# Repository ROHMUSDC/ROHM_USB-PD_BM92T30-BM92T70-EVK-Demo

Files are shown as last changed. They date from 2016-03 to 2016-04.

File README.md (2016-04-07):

# ROHM USB-PD DP Alt Mode EVK - DP/USB3.0 Source and Sink Demonstrations
* PN: BM92T30-HOST-EVK-101 (occasionally referred to as "EVK1")
* PN: BM92T70-DEVICE-EVK-101 (occasionally referred to as "EVK2")
* Description:  This Evaluation Kit will demonstrate ROHM's USB-PD Solution in conjunction with Pericom's SS MUX to provide a USB-PD Solution for USB Type C Applications
* Developer: USDC Applications Engineering Team, ROHM Semiconductor
* Repository Generated: April 2016

----
### General Information
* If you have any questions about any of this technical information, please feel free to reach out to us as engineering@rohmsemiconductor.com
* Please note that detailed technical notes explaining the USB-PD IC register mapping is not available for this IC in this repository and requires an NDA with ROHM for this information.
	* Please reach out to your ROHM sales manager, visit https://www.rohm.com/web/global/contactus or send a message to engineering@rohmsemiconductor.com to establish this NDA for additional information.

----
### Repository Contents
* Documentation Folder: Contains the latest HW PDF files, USB-PD General Datasheets, and Board Manual
* Hardware Design Files: Contains the Schematic/BOM/Gerber Source files for these EVK development boards

-----
### Video Demonstrations

* ROHM Evaluation Board Video Demo, BM92T30-HOST-EVK-101 (April 2016):
	* https://youtu.be/YEIDfTC97i4

* ROHM Evaluation Board Video Demo, BM92T70-DEVICE-EVK-101 (April 2016):
	* https://youtu.be/2LjfqHi3JEg 

* ROHM USBPD Type-C Alt Mode Demo PART1: DisplayPort Monitor Connection Demo (OLD-Live Demo, From 2015)
	* https://www.youtube.com/watch?v=6yjsj-j72X8

* ROHM USBPD Type-C Alt Mode Demo PART2: USB3.0 Super Speed Demo (OLD-Live Demo, From 2015)
	* https://www.youtube.com/watch?v=sI1nSPhlAow

-----
### Frequently Asked Questions (FAQ)
* Q: For EVK2, the documentation refers to REV04 but the design files listed here are REV05.  What is the difference.
* A: REV05 and REV04 are functionally identical.  Only change between EVK2 REV04 and REV05 is a fix of a broken net that was missed during the development of these boards.

----
### DISCLAIMER
This Technical Data is protected under copyright laws.

ROHM hereby grants you a nonexclusive, nontransferable license to use this Technical Data 
as long as you abide by the terms and conditions of this DISCLAIMER. 

However, you are not authorized to sell, loan, rent, lease, redistribute or license this Technical Data, 
in whole or in part, or in modified form, to anyone.

You may modify this Technical Data to suit your specific applications, 
but the rights to derivative works and said modifications shall belong to ROHM. 

You may make copies of this Technical Data as necessary for internal use only within your company.

ROHM shall not be responsible for ensuring proper application on all computer systems.
This Technical Data is provided AS IS. ROHM makes no guarantees, either implicitly or explicitly, 
regarding its usability, functionality, accuracy, merchantability, or fitness for a specific purpose.

In addition, you shall take full responsibility for the use of any information acquired from this Technical Data. 

ROHM does not assume warranty of any kind arising from the use of this Technical Data. ACCORDINGLY, 
IN NO EVENT SHALL ROHM BE RESPONSIBLE, WHETHER THROUGH CONTRACT OR TORT LIABILITY, 
FOR ANY DAMAGES (INCLUDING BUT NOT LIMITED TO LOST PROFITS OR OTHER INCIDENTAL, CONSEQUENTAL, 
OR PUNITIVE DAMAGES) ARISING OUT OF OR IN CONNECTION WITH THE USE OR APPLICATION OF THIS Technical Data.

Furthermore, this Technical Data is subject to change without notice.

Unless otherwise expressly provided herein, ROHM does not convey any license under patent rights 
or any other intellectual property rights (including those of third parties).

ROHM is not obligated to provide maintenance or support for the Technical Data.

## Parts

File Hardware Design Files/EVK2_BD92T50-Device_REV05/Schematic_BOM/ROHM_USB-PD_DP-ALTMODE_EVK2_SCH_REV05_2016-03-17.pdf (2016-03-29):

# ROHM USB-PD Type-C DP Alt Mode EVK2 - Device/UFP

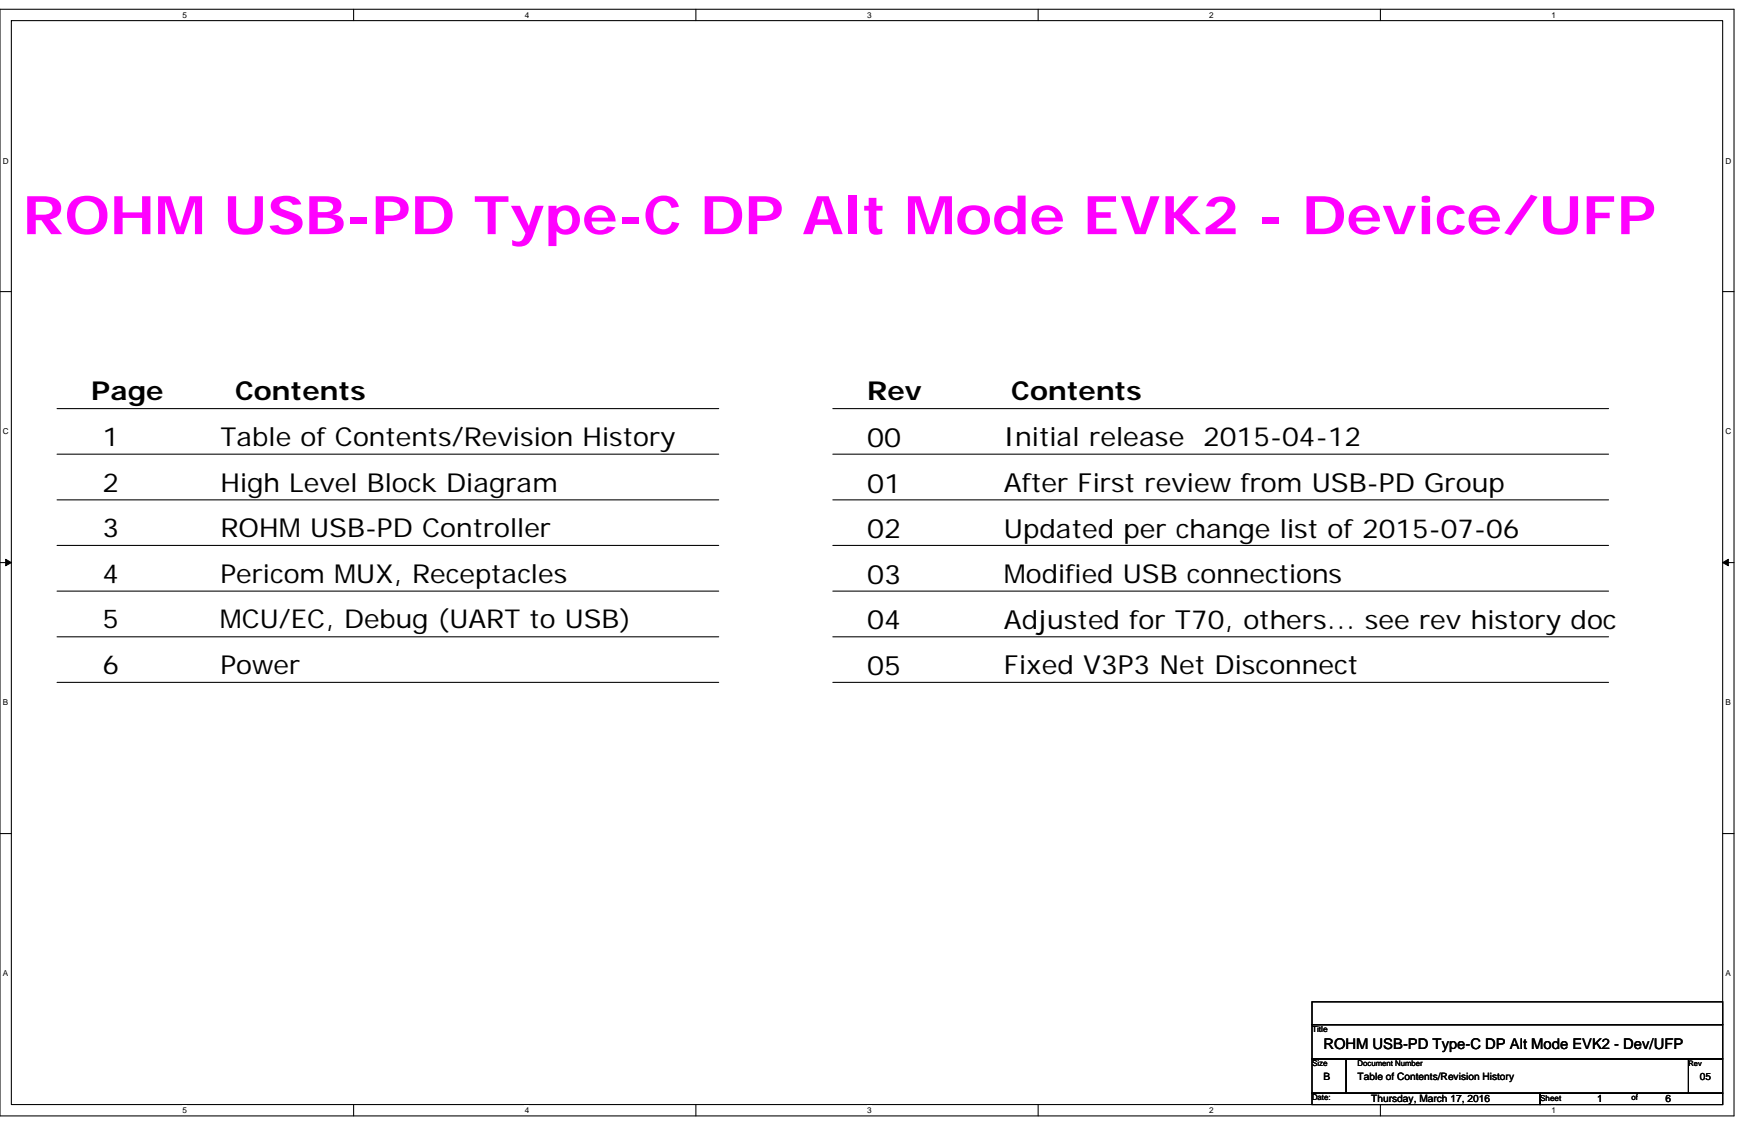
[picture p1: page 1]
Page; Contents; Table of Contents/Revision History; ROHM USB-PD Controller; Pericom MUX, Receptacles; Rev; Initial release 2015-04-12; MCU/EC, Debug (UART to USB); After First review from USB-PD Group; Updated per change list of 2015-07-06; Modified USB connections; Adjusted for T70, others... see rev history doc; Power; High Level Block Diagram; Fixed V3P3 Net Disconnect

Title
ROHM USB-PD Type-C DP Alt Mode EVK2 - Dev/UFP

Size Size Size B B B | Document Number Document Number Document Number Table of Contents/Revision History Table of Contents/Revision History Table of Contents/Revision History | Rev Rev Rev 05 05 05

Date: Date: Date: Thursday, March 17, 2016 Thursday, March 17, 2016 Thursday, March 17, 2016 | Sheet Sheet Sheet 1 1 1 of of of 6 6 6

5

4

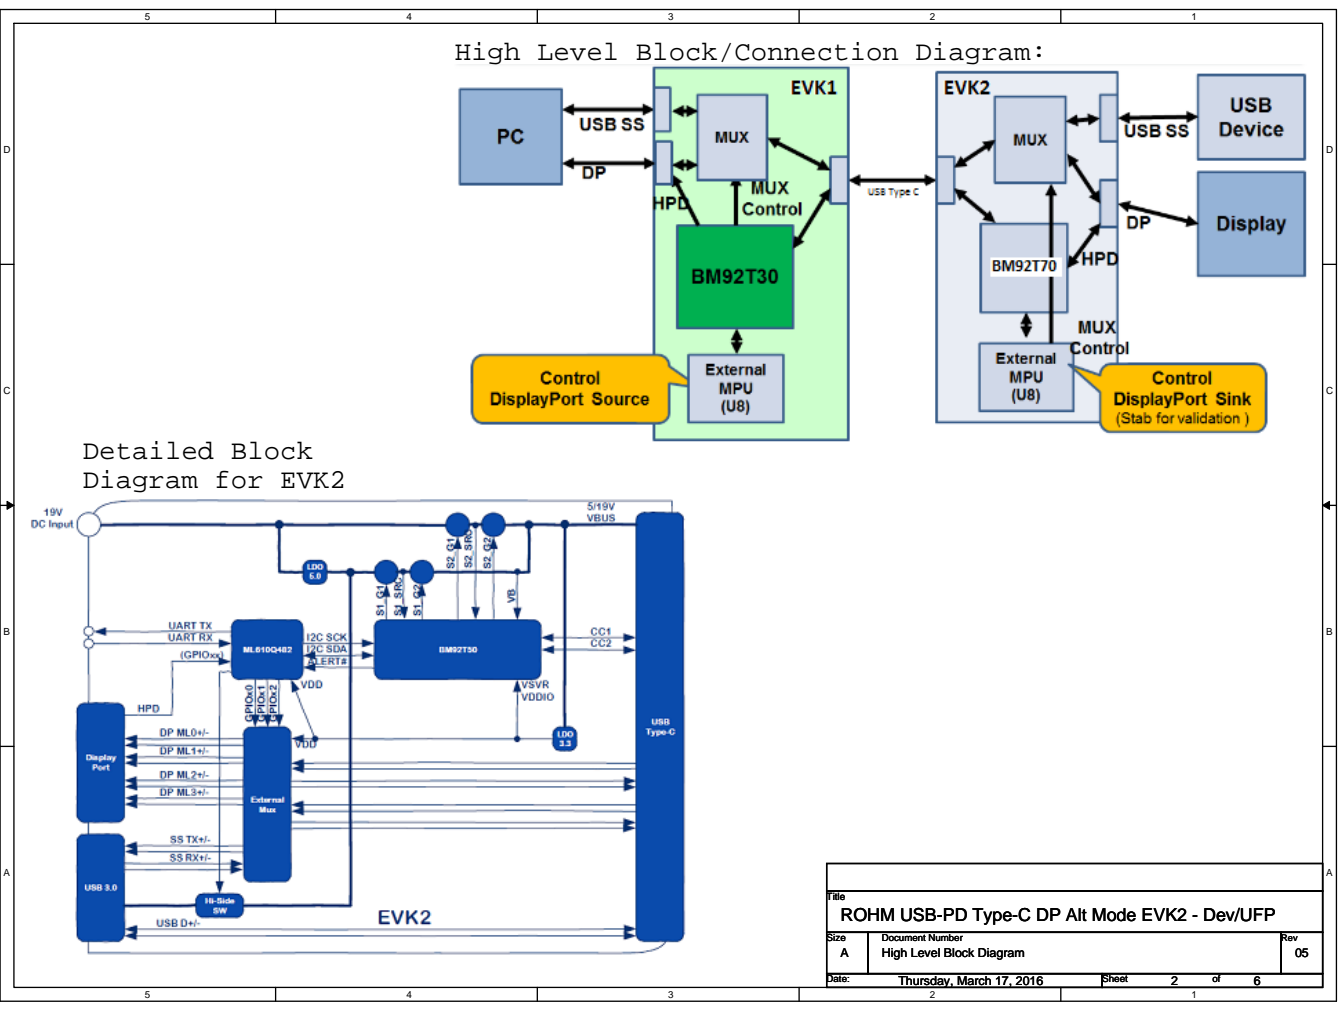
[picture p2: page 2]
Detailed Block Diagram for EVK2

High Level Block/Connection Diagram:

Title
ROHM USB-PD Type-C DP Alt Mode EVK2 - Dev/UFP

Size Size Size A A A | Document Number Document Number Document Number High Level Block Diagram High Level Block Diagram High Level Block Diagram | Rev Rev Rev 05 05 05

Date: Date: Date: Thursday, March 17, 2016 Thursday, March 17, 2016 Thursday, March 17, 2016 | Sheet Sheet Sheet 2 2 2 of of of 6 6 6

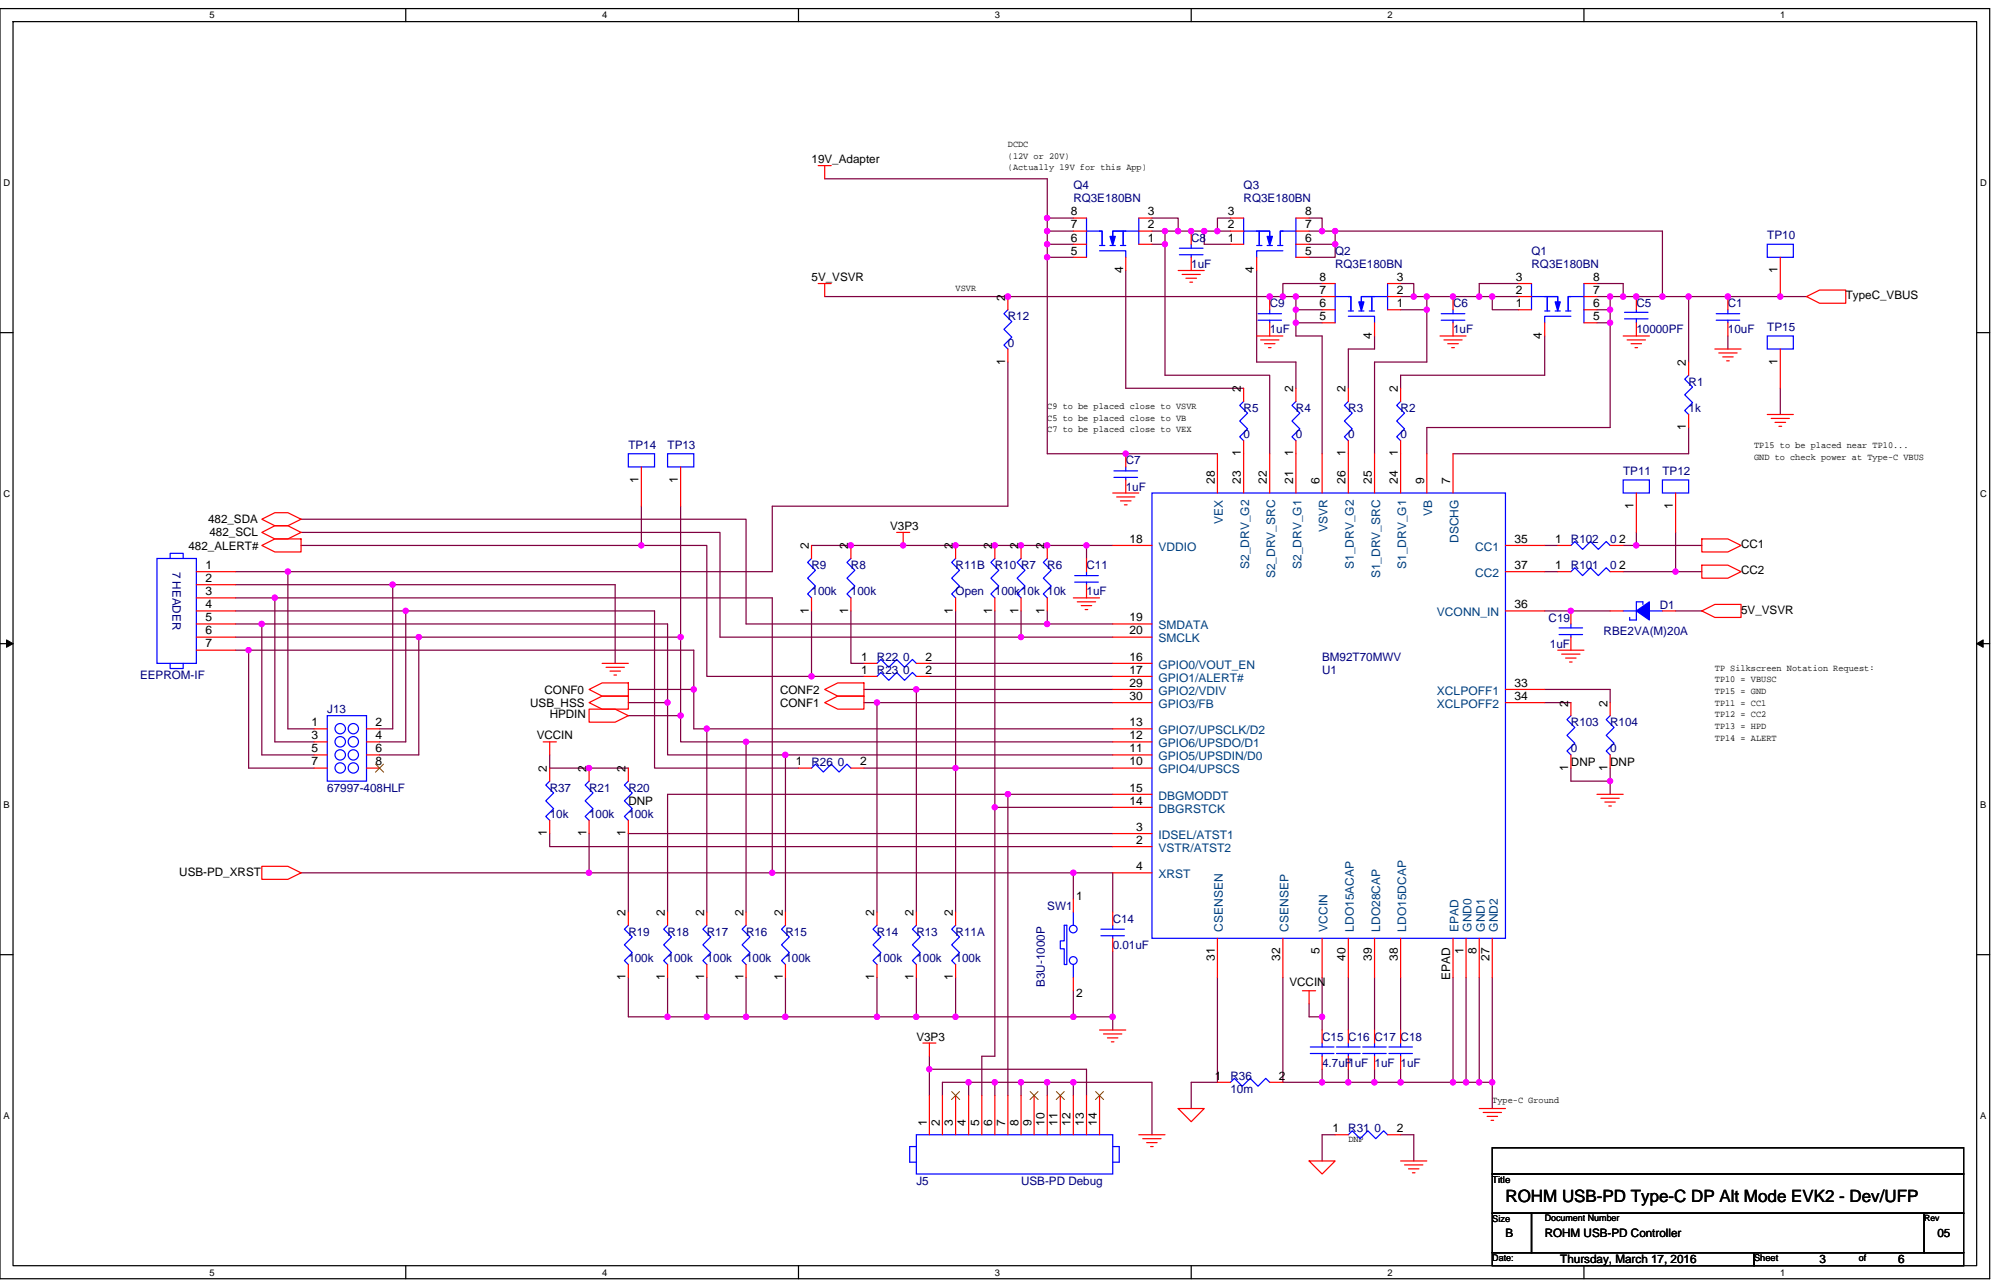
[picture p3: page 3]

DCDC
(Actually 19V for this App)

C9 to be placed close to VSVR
C5 to be placed close to VB
C7 to be placed close to VEX

TP15 to be placed near TP10...
GND to check power at Type-C VBUS

GPIO1/ALERT# 17
GPIO2/VDIV 29 GPIO3/FB 30

DBGRSTCK 14 DBGMODDT 15

VSTR/ATST2 2 IDSEL/ATST1 3

VCCIN | C15 | C16 | C17 | C18

Title
ROHM USB-PD Type-C DP Alt Mode EVK2 - Dev/UFP

Size Size Size B B B | Document Number Document Number Document Number ROHM USB-PD Controller ROHM USB-PD Controller ROHM USB-PD Controller | Rev Rev Rev 05 05 05

Date: Date: Date: Thursday, March 17, 2016 Thursday, March 17, 2016 Thursday, March 17, 2016 | Sheet Sheet Sheet 3 3 3 of of of 6 6 6

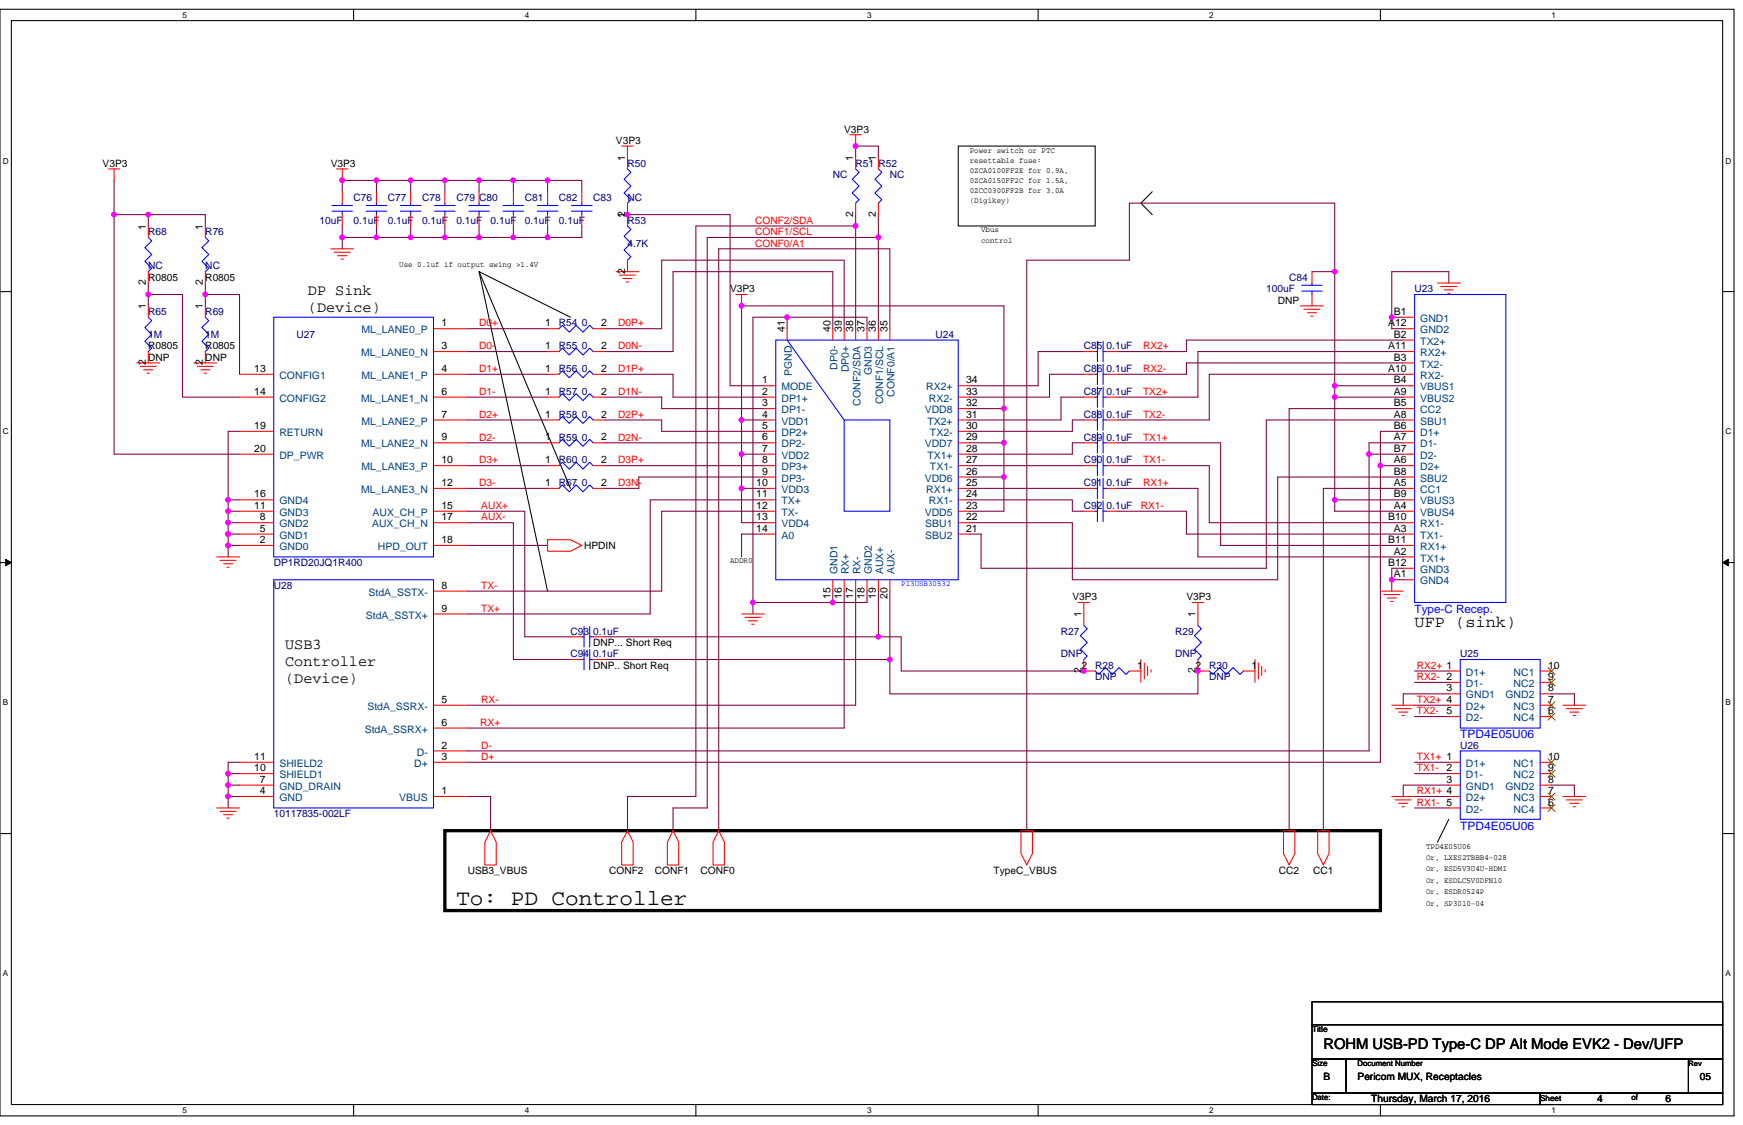
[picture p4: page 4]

Use 0.1uf if output swing >1.4V

Title
ROHM USB-PD Type-C DP Alt Mode EVK2 - Dev/UFP

Size Size Size B B B | Document Number Document Number Document Number Pericom MUX, Receptacles Pericom MUX, Receptacles Pericom MUX, Receptacles | Rev Rev Rev 05 05 05

Date: Date: Date: Thursday, March 17, 2016 Thursday, March 17, 2016 Thursday, March 17, 2016 | Sheet Sheet Sheet 4 4 4 of of of 6 6 6

# MCU - Acting EC for the USB-PD IC

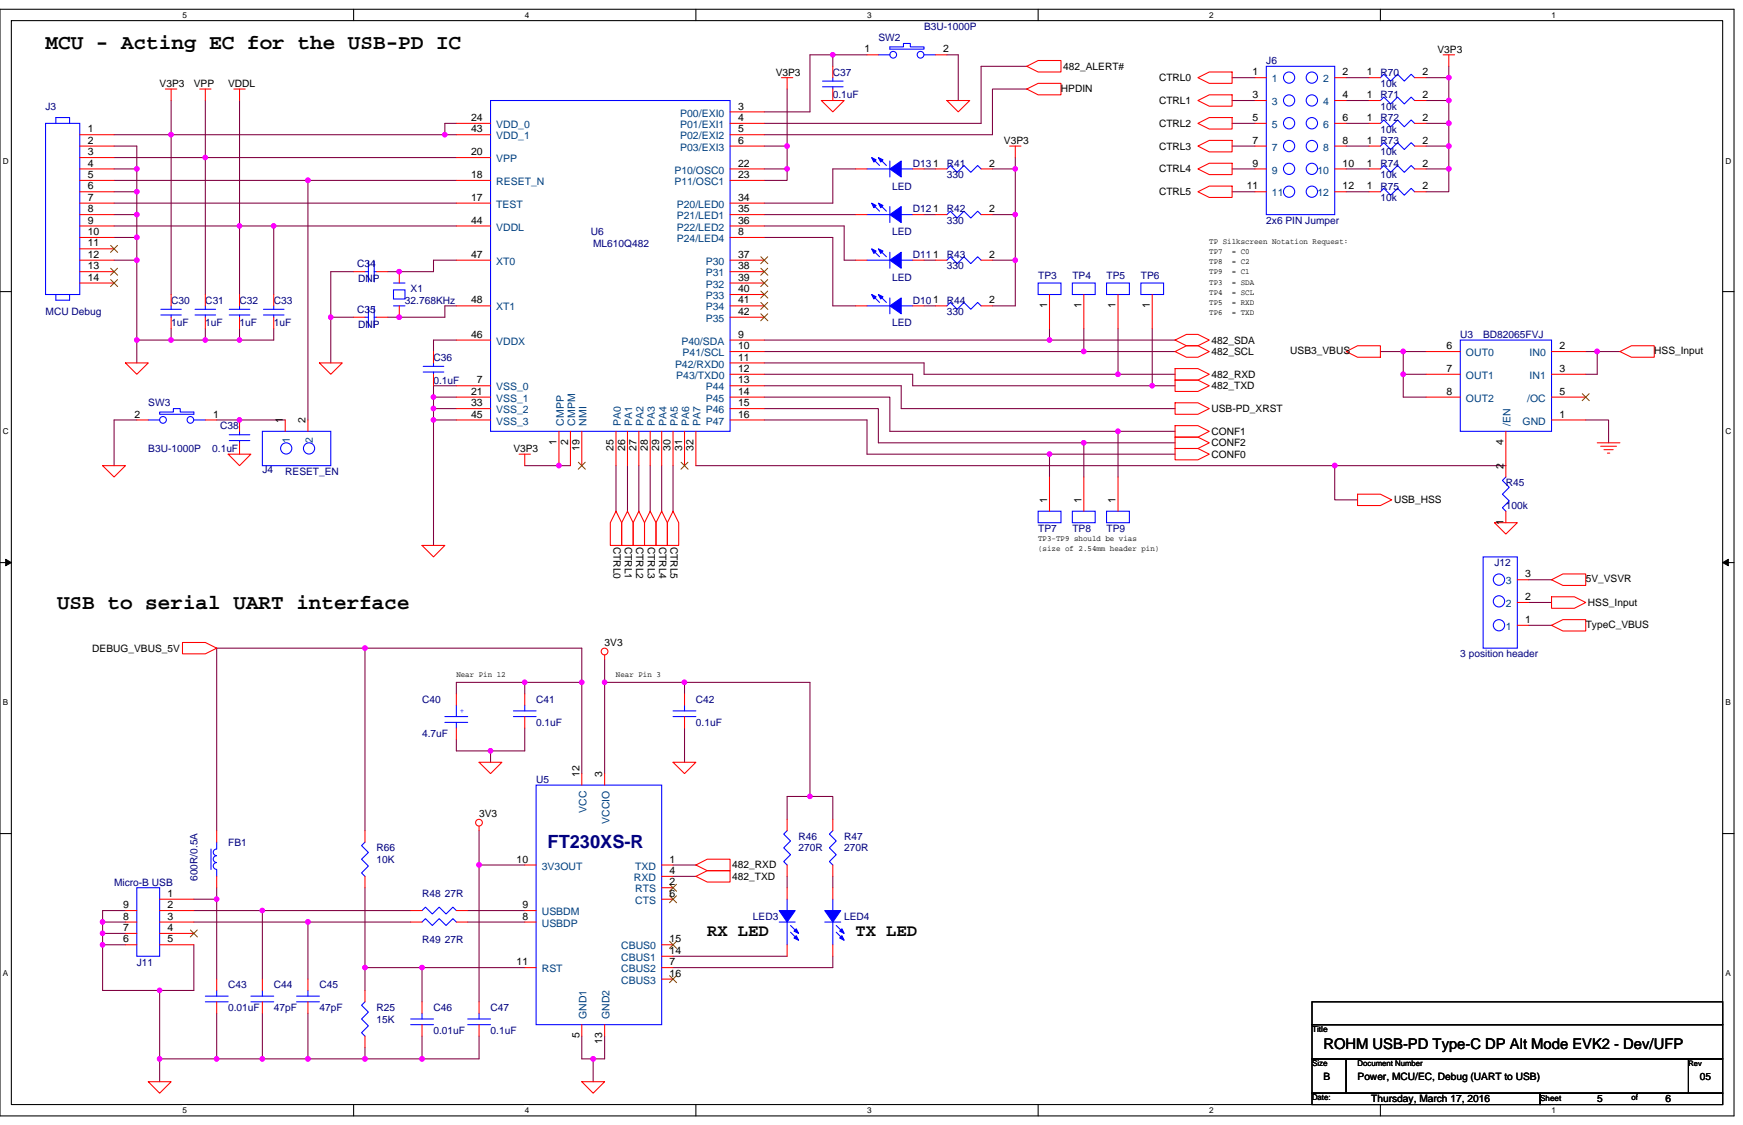
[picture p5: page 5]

TP3-TP9 should be vias
(size of 2.54mm header pin)

USB to serial UART interface

Title
ROHM USB-PD Type-C DP Alt Mode EVK2 - Dev/UFP

Size Size Size B B B | Document Number Document Number Document Number Power, MCU/EC, Debug (UART to USB) Power, MCU/EC, Debug (UART to USB) Power, MCU/EC, Debug (UART to USB) | Rev Rev Rev 05 05 05

Date: Date: Date: Thursday, March 17, 2016 Thursday, March 17, 2016 Thursday, March 17, 2016 | Sheet Sheet Sheet 5 5 5 of of of 6 6 6

5

4

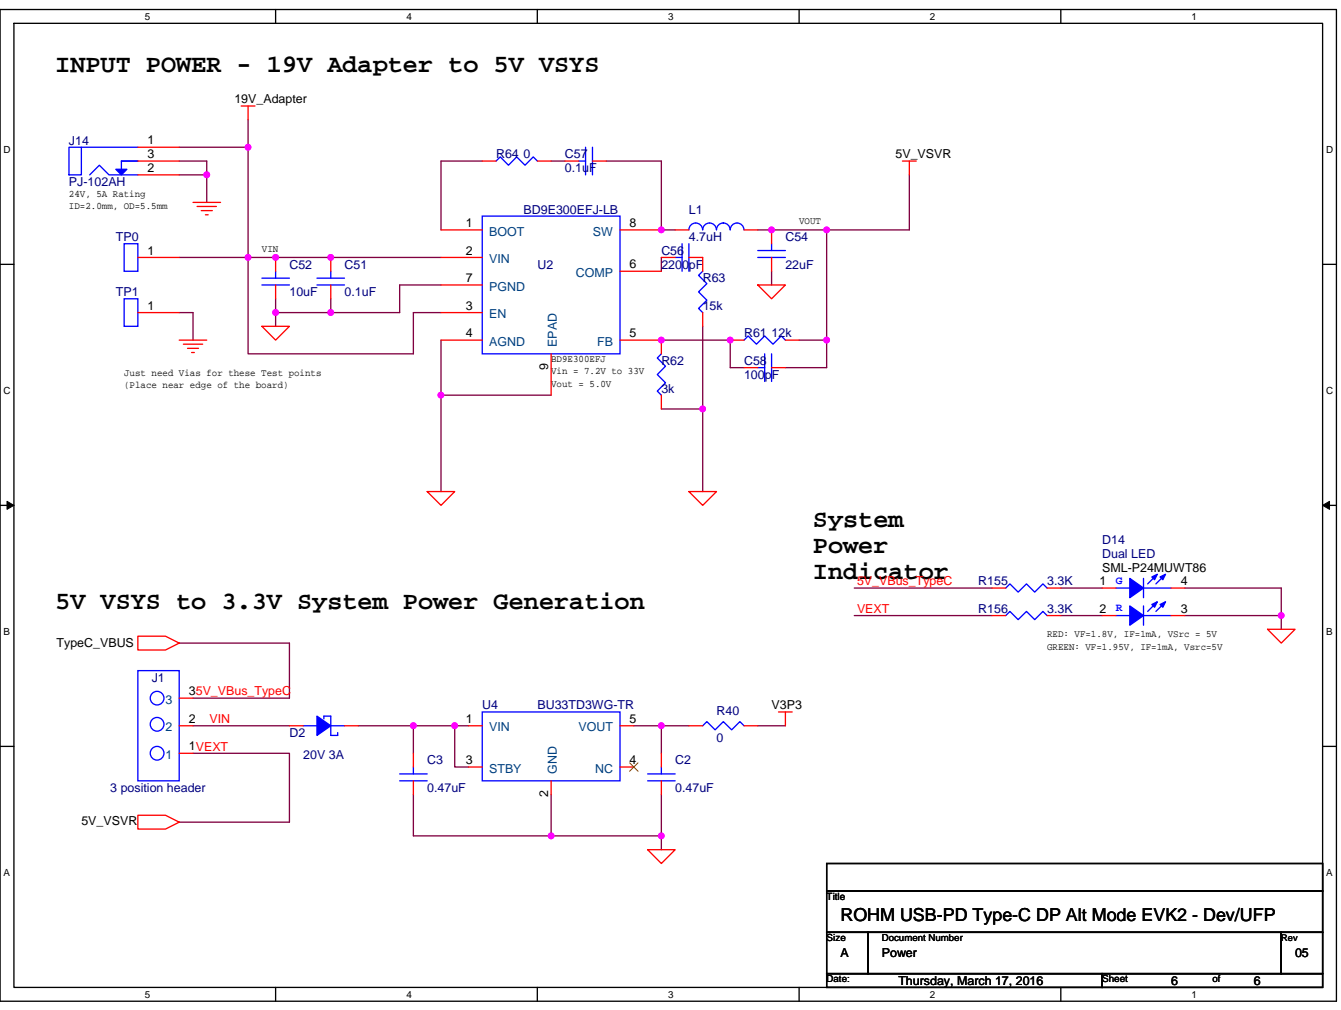
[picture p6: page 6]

INPUT POWER - 19V Adapter to 5V VSYS 19V_Adapter

PGND 7

Just need Vias for these Test points
(Place near edge of the board)

5V VSYS to 3.3V System Power Generation

RED: VF=1.8V, IF=1mA, VSrc = 5V
GREEN: VF=1.95V, IF=1mA, Vsrc=5V

Title
ROHM USB-PD Type-C DP Alt Mode EVK2 - Dev/UFP

Size Size Size A A A | Document Number Document Number Document Number Power Power Power | Rev Rev Rev 05 05 05

Date: Date: Date: Thursday, March 17, 2016 Thursday, March 17, 2016 Thursday, March 17, 2016 | Sheet Sheet Sheet 6 6 6 of of of 6 6 6

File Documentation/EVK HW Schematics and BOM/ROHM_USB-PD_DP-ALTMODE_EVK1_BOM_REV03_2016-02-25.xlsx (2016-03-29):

ROHM USB-PD Type-C DP Alt Mode EVK1 - Host/DFP Revised: Jan 21, 2016
Bill Of Materials
Item | Quantity | Reference | Part | PCB Footprint | DESCRIPTION | MANUFACTURER1 | MANUFACTURER1_PART# | Disty PN | Where to Source | QTY Required for 20 | QTY Required for 50 | DNP | Comments
1 | 1 | C1 | 10uF | C1206 | 10uF, 3216, X5R, 50V | Murata | GRM31CR61H106KA12L | 490-5961-1-ND | Digikey | 22 | 55
2 | 2 | C2,C3 | 0.47uF | C0402 | CAP CER 0.47UF 6.3V 10% X5R 0402 | Samsung | CL05A474KQ5NNNC | 1276-1479-1-ND | Digikey | 44 | 110
3 | 2 | C5,C14 | 0.01uF | C0402 | 0.01uF, 1005, X5R, 50V | TDK | CGA2B3X5R1H103K050BB | 445-12201-1-ND | Digikey | 44 | 110
4 | 7 | C6,C7,C12,C30,C31,C32,C33 | 1uF | C0603 | 1uF, 1608, X5R, 50V | TAIYO YUDEN | UMK107BJ105KA-T | 587-2400-1-ND | Digikey | 154 | 385
5 | 8 | C8,C9,C10,C11,C16,C17,C18,C19 | 1uF | C0402 | 1uF, 1005, X5R, 16V | Murata | GRM155R61C105ME01D | 490-10454-1-ND | Digikey | 176 | 440
6 | 1 | C15 | 4.7uF | C0402 | 4.7uF, 1005, X5R, 6.3V | TAIYO YUDEN | JMK105BBJ475MV-F | 587-2787-1-ND | Digikey | 22 | 55
7 | 18 | C36,C37,C38,C77,C78,C79,C80,C81,C82,C83,C85,C86,C87,C88,C89,C90,C91,C92 | 0.1uF | C0402 | CAP CER 0.1UF 10V 10% X5R 0402 | Murata | GRM155R61A104KA01D | 490-1318-1-ND | Digikey | 396 | 990
8 | 1 | C40 | 4.7uF | ECE-V1EA4R7SR | Cap, Polarized, 4.7uF | Panasonic | EEE-1EA4R7SR | PCE3910CT-ND | Digikey | 22 | 55
9 | 3 | C41,C42,C47 | 0.1uF | C0805 | Cap, Ceramic 0.1uF 0805 | TDK | C2012X7R2A104K | 445-1418-1-ND | Digikey | 66 | 165
10 | 2 | C43,C46 | 0.01uF | C0805 | Cap, Ceramic, 0.01uF 0805 | TDK | C2012X7R2E103K | 445-2280-1-ND | Digikey | 44 | 110
11 | 2 | C44,C45 | 47pF | C0805 | Cap, Ceramic, 47pF 0805 | Kemet | C0805C470J1GACTU | 399-8079-1-ND | Digikey | 44 | 110
12 | 1 | C76 | 10uF | C0603 | CAP CER 10UF 6.3V 20% X5R 0603 | Murata | GRM188R60J106ME47J | 490-6405-1-ND | Digikey | 22 | 55
13 | 1 | D1 | RBE2VA(M)20A | RBE2VAM20A | Schottky barrier diode,20V/2A Vf=0.46(2A)/0.39(1A) | ROHM | RBE2VA20ATR | N/A | Direct Sample from ROHM | 22 | 55
14 | 1 | D2 | 20V 3A | SOD-123F | DIODE SCHOTTKY 20V 3A PMDU | ROHM | RB051M-2YTR | N/A | Direct Sample from ROHM | 22 | 55
15 | 4 | D10,D11,D12,D13 | LED | LED0402 | LED 0402 RED 50MW 20MA SMD | ROHM | SML-P11VTT86 | N/A | Direct Sample from ROHM | 88 | 220
16 | 1 | D14 | Dual LED | LED0404-DUAL | LED PICOLED DUAL YWGN/RED 1010 | ROHM | SML-P24MUWT86 | N/A | Direct Sample from ROHM | 22 | 55
17 | 1 | EEPROM-IF | 7 HEADER | SM07B-SRSS-TB | 7pin connector | JST | SM07B-SRSS-TB(LF)(SN) | 455-1807-1-ND | Digikey | 22 | 55
18 | 1 | FB1 | 600R/0.5A | FB0805 | Ferrite Bead (600R/0.5A) | Laird | MI0805K601R-10 | 240-2390-1-ND | Digikey | 22 | 55
19 | 1 | J1 | 3 position header | HDR_THVT_1X3_100 | BERGSTIK II .100" SR STRAIGHT | FCI | 68000-103HLF | 609-3461-ND | Digikey | 22 | 55
20 | 2 | J2,J4 | 2 position header | HDR_THVT_1X2_100 | BERGSTIK II .100" SR STRAIGHT | FCI | 68000-102HLF | 609-3500-ND | Digikey | 44 | 110
21 | 1 | J3 | MCU Debug | HDR_THVT_2x7_100 | ThroughHole - 2x7 | FCI | 67996-114HLF | 609-3491-ND | Digikey | 22 | 55
22 | 1 | J5 | USB-PD Debug | HDR_THVT_2x7_100 | ThroughHole - 2x7 | FCI | 67996-114HLF | 609-3491-ND | Digikey | 22 | 55
23 | 1 | J11 | Micro-B USB | ZX62R-B-5P | micro USB receptacle | Hirose | ZX62R-B-5P | H11574CT-ND | Digikey | 22 | 55
24 | 1 | J12 | 67997-408HLF | HDR_2X4_100_VERT | CONN HEADER 8POS .100 STR TIN | FCI | 67997-408HLF | 609-3397-ND | Digikey | 22 | 55
25 | 1 | LED3 | Green | LED0805 | LED 570NM GREEN WTR CLR 0805 SMD | ROHM | SML-210MTT86 | N/A | Direct Sample from ROHM | 22 | 55
26 | 1 | LED4 | Yellow | LED0805 | LED 585NM YLW WTR CLR 0805 SMD | ROHM | SML-210YTT86 | N/A | Direct Sample from ROHM | 22 | 55
27 | 2 | Q1,Q2 | RQ3E180BN | RQ3E180BN | MOS FET N-ch 3.0×3.0×1.0, TR_HSMT8 | ROHM | RQ3E180BN | N/A | Direct Sample from ROHM | 44 | 110
28 | 1 | Q3 | QS8K13 | QS8K13 | MOS FET N-ch 2.8×3.0×0.6, TSMT8 | ROHM | QS8K13 | N/A | Direct Sample from ROHM | 22 | 55
29 | 1 | R1 | 1k | R0603 | 1k,1608 | ROHM | MCR03EZPFX1001 | N/A | Direct Sample from ROHM | 22 | 55
30 | 6 | R2,R3,R4,R5, C93, C94 | 0 | R0402 | 0, 1005 | ROHM | MCR01MRTJ000 | N/A | Direct Sample from ROHM | 132 | 330
31 | 3 | R6,R7,R37 | 10k | R0402 | 10k, 1005 | ROHM | MCR01MRTF1002 | N/A | Direct Sample from ROHM | 66 | 165
32 | 14 | R8,R9,R10,R11A,R13,R14,R15B,R16B,R17B,R18,R19,R21,R31,R32 | 100k | R0402 | 100k, 1005 | ROHM | MCR01MRTF1003 | N/A | Direct Sample from ROHM | 308 | 770
33 | 6 | R12,R22,R23,R26,R101,R102 | 0 | R0603 | RES 0.0 OHM 1/10W JUMP 0603 SMD | ROHM | MCR03ERTJ000 | N/A | Direct Sample from ROHM | 132 | 330
34 | 1 | R25 | 15K | R0805 | Resistor, 15kOhm 0805 | ROHM | MCR10ERTF1502 | N/A | Direct Sample from ROHM | 22 | 55
35 | 1 | R40 | 0 | R0603 | RES 0.0 OHM 1/10W JUMP 0603 SMD | Rohm | MCR03ERTJ000 | N/A | Direct Sample from ROHM | 22 | 55
36 | 4 | R41,R42,R43,R44 | 330 | R0402 | RES 330 OHM 1/16W 5% 0402 SMD | ROHM | MCR01MRTJ331 | N/A | Direct Sample from ROHM | 88 | 220
37 | 1 | R45 | 10K | R0805 | Resistor, 10kOhm 0805 | ROHM | MCR10EZPF1002 | N/A | Direct Sample from ROHM | 22 | 55
38 | 2 | R46,R47 | 270 | R0402 | Resistor, 270ohm 0402 | ROHM | MCR01MRTJ271 | N/A | Direct Sample from ROHM | 44 | 110
39 | 2 | R48,R49 | 27 | R0402 | Resistor, 27ohm 0402 | ROHM | MCR01MRTJ270 | N/A | Direct Sample from ROHM | 44 | 110
40 | 1 | R53 | 4.7K | R0402 | 4.7k, 0402 | ROHM | MCR01MRTJ472 | N/A | Direct Sample from ROHM | 22 | 55
41 | 10 | R54,R55,R56,R57,R58,R59,R60,R61,R62,R63 | 0 | R0402 | RES 0 OHM 1/16W 5% 0402 SMD | ROHM | MCR01MRTJ000 | N/A | Direct Sample from ROHM | 220 | 550
42 | 2 | R155,R156 | 3.3K | R0402 | RES SMD 3.3K OHM 1% 1/16W 0402 | ROHM | MCR01MRTF3301 | N/A | Direct Sample from ROHM | 44 | 110
43 | 3 | SW1,SW2,SW3 | B3U-1000P | B3U-1000P | Tact switch | Omron | B3U-1000P | SW1020CT-ND | Digikey | 66 | 165
44 | 1 | U1 | BM92T30MWV | BM92T30MWV | TYPE-C USB PD Controller | ROHM | BM92T30MWV | N/A | Direct Sample from ROHM | 22 | 55
45 | 1 | U2 | BD82065FVJ | BD82065FVJ | USB Hiside switch | ROHM | BD82065FVJ | N/A | Direct Sample from ROHM | 22 | 55
46 | 1 | U4 | BU33TD3WG-TR | SSOP5 | IC REG LDO 3.3V 0.2A SSOP5 | ROHM | BU33TD3WG-TR | N/A | Direct Sample from ROHM | 22 | 55
47 | 1 | U5 | FT230XS-R | FT230XS-R | USB-to-UART Translator | FTDI | FT230XS-R | 768-1135-1-ND | Digikey | 22 | 55
48 | 1 | U6 | ML610Q482 | ML610Q482 | 8-bit CMOS microcontroller | Lapis | ML610Q482 | N/A | Direct Sample from ROHM | 22 | 55
49 | 1 | U23 | Type-C recep. | DX07B024JJ1-S | USB Type-C Receptacle | JAE | DX07B024JJ1-S | 656-DX07B024JJ1R1500 | Mouser | 22 | 55
50 | 1 | U24 | PI3USB30532 | PI3USB30532 | MUX 40pin TQFN, 3x6mm | PERICOM | PI3USB30532 | N/A | Direct Sample from Pericom | 22 | 55
51 | 2 | U25,U26 | TPD4E05U06 | TPD4E05U06 | ESD Protection Device for Super-Speed (up to 6 GBPS) Interface | TI | TPD4E05U06 | 595-TPD4E05U06DQAR | Mouser | 44 | 110
52 | 1 | U27 | DP1RD20JQ1R400 | DP1RD20JQ1R400 | CONN RCPT 20POS R/A TOP MT GOLD | JAE | DP1RD20JQ1R400 | 670-2589-1-ND | Digikey | 22 | 55
53 | 1 | U28 | E8199-030-01 | E8199-030-01 | CONN USB 3.0 B RCPT R/A THT | Pulse Electronics Corporation | E8199-030-01 | 553-2263-ND | Digikey | 22 | 55
54 | 1 | X1 | 32.768KHz | AB26T-32p768KHZ | OSC, 32.768kHz | Abracon LLC | AB26T-32.768KHZ | 535-9032-ND | Digikey | 22 | 55
55 | 1 | C84 | 100uF | C1206 | CAP CER 100UF 6.3V 20% X5R 1206 | Murata | GRM31CR60J107ME39K | 490-7217-1-ND | Digikey | 22 | 55 | DNP | DNP
56 | 4 | R15A,R16A,R17A,R20 | 100k | R0402 | 100k, 1005 | ROHM | MCR01MRTF1003 | N/A | Direct Sample from ROHM | 88 | 220 | DNP | DNP
57 | 4 | R27,R28,R29,R30 | 0 | R0402 | RES 0 OHM 1/16W 5% 0402 SMD | ROHM | MCR01MRTJ000 | N/A | Direct Sample from ROHM | 88 | 220 | DNP | DNP
58 | 1 | R11B | Open | R0603 | 1608, Need foot pattern | ROHM | N/A | N/A | Direct Sample from ROHM | 22 | 55 | DNP | DNP
59 | 2 | C34,C35 | DNP | C0603 | Cap, DNP (please leave 1608 footprint) | N/A | N/A | N/A | DNP | 44 | 110 | DNP | DNP
60 | 3 | R50,R51,R52 | NC | R0402 | No Connect (generate footprint, 0402) | N/A | N/A | N/A | DNP | 66 | 165 | DNP | DNP
61 | 16 | TP0,TP1,TP2,TP3,TP4,TP5,TP6,TP7,TP8,TP9,TP10,TP11,TP12,TP13,TP14,TP15 | TEST POINT | TP_D040C055 | No Connect | N/A | N/A | N/A | DNP | 352 | 880 | DNP | DNP
62 | 4 | Corner Standoffs | STANDOFF | 150 MIL Drill Hole | HEX STANDOFF M3 ALUMINUM 10MM | Keystone Electronics | 24433 | 36-24433-ND | Digikey | 88 | 220
63 | 4 | Corner Standoffs Screws | SCREW | 150 MIL Drill Hole | Metric JIS Pan Head Phillips Machine Screw, Zinc-Plated Steel, M3 Size, 6mm Length, .5mm Pitch | McMaster-Carr | 94387A206 | 94387A206 | McMaster-Carr | 88 | 220

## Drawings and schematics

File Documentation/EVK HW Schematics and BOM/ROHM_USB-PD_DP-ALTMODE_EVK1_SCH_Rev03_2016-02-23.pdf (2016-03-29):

# ROHM USB-PD Type-C DP Alt Mode EVK1 - Host/DFP

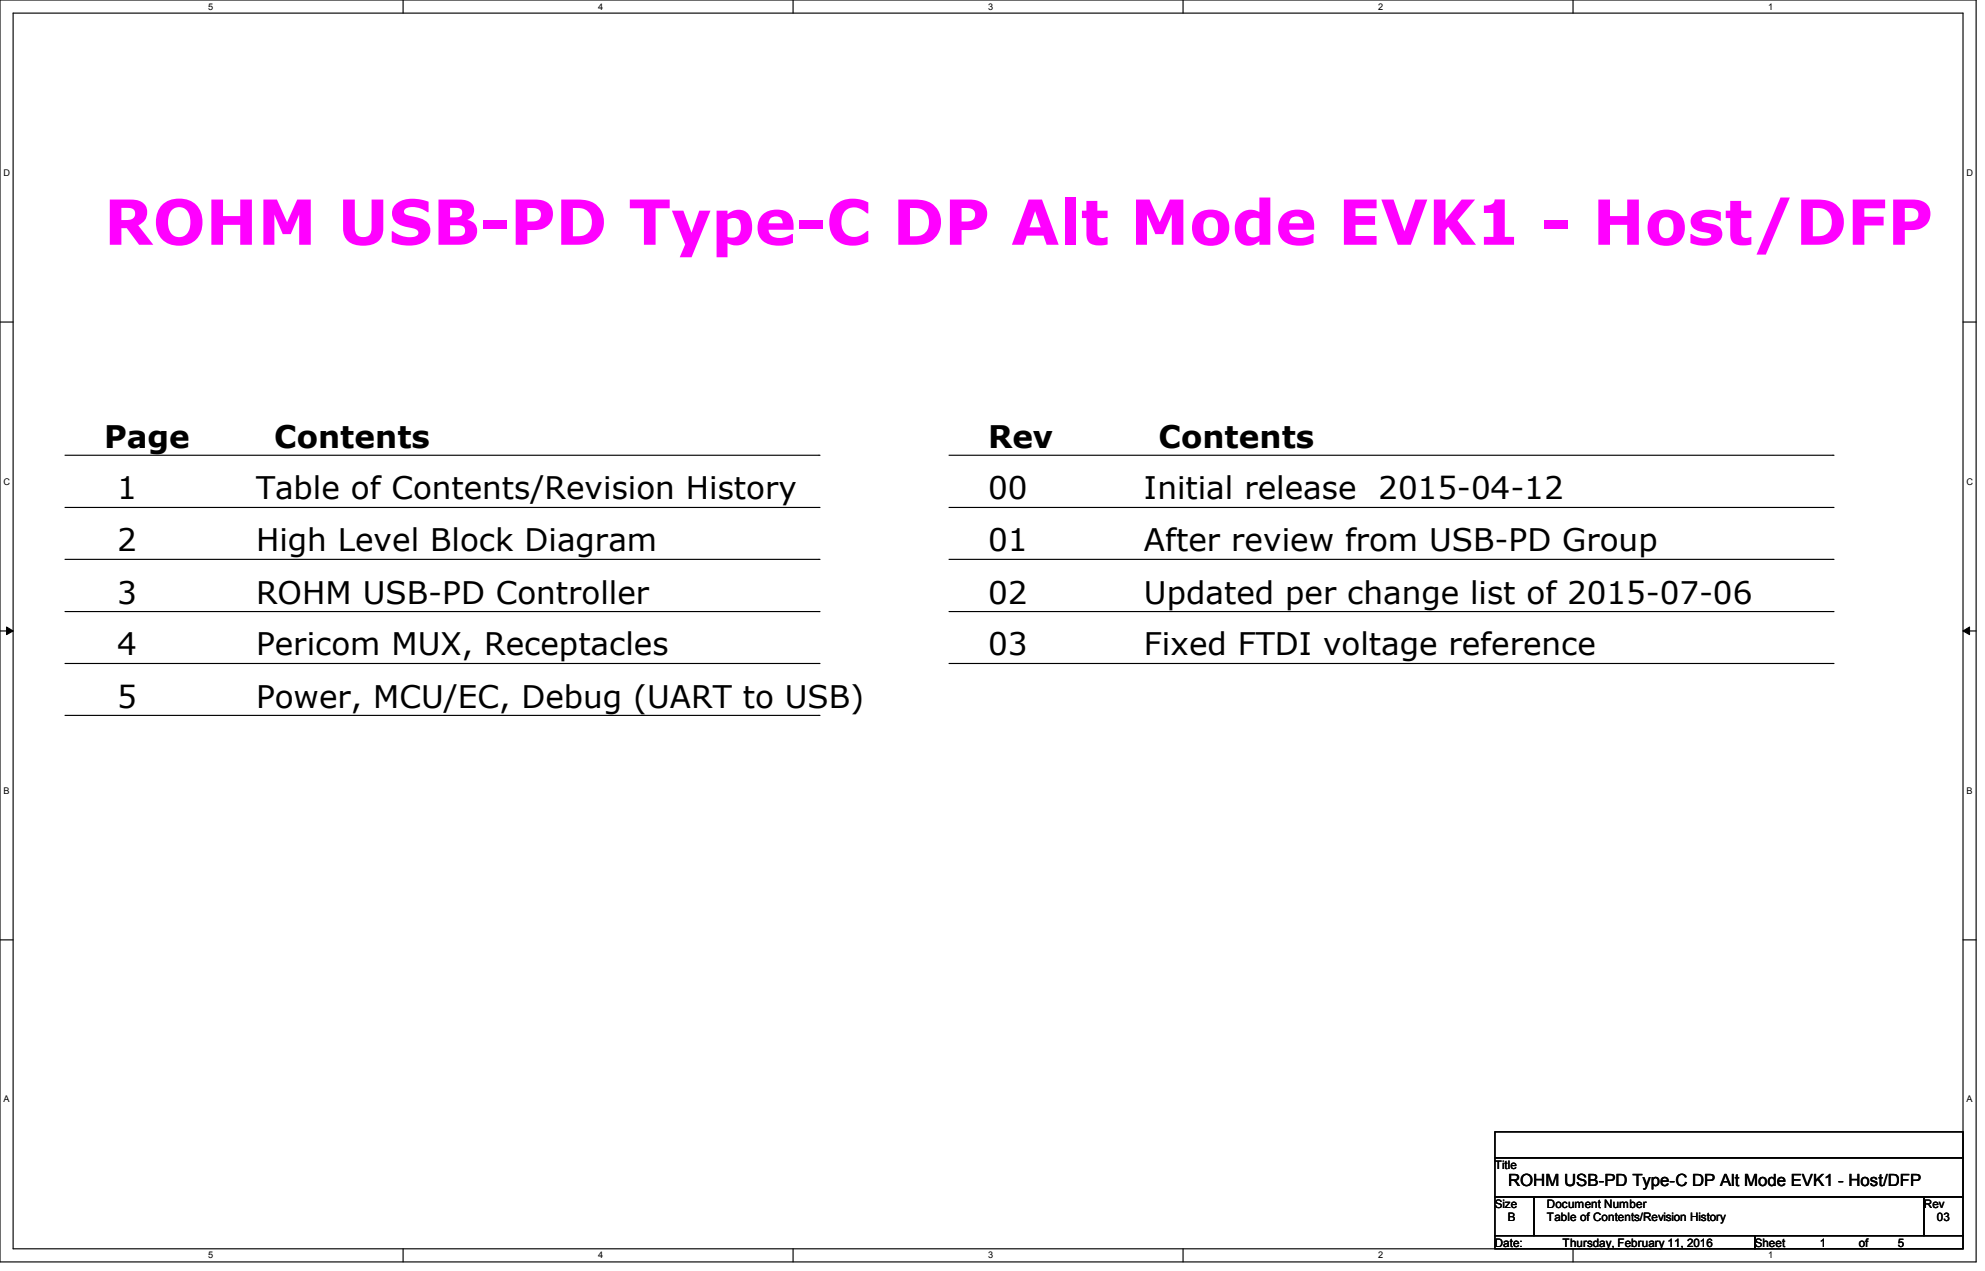
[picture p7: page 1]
Page; Contents; Table of Contents/Revision History; ROHM USB-PD Controller; Pericom MUX, Receptacles; Rev; Initial release 2015-04-12; Power, MCU/EC, Debug (UART to USB); After review from USB-PD Group; Updated per change list of 2015-07-06; Fixed FTDI voltage reference; High Level Block Diagram; Size; Document Number; Date:; Sheet; Thursday, February 11, 2016

Title
ROHM USB-PD Type-C DP Alt Mode EVK1 - Host/DFP

# High Level Block/Connection Diagram:

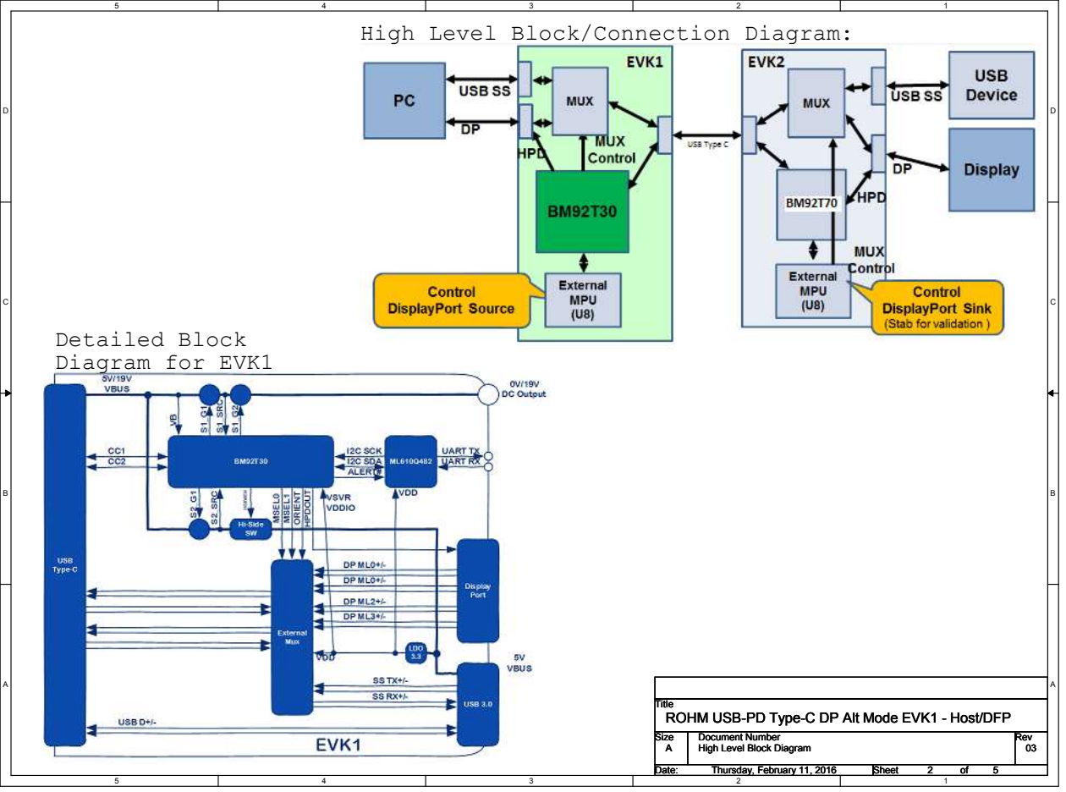
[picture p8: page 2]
Detailed Block Diagram for EVK1; Size; Document Number; Rev; Date:; Sheet; High Level Block Diagram; Thursday, February 11, 2016

Title
ROHM USB-PD Type-C DP Alt Mode EVK1 - Host/DFP

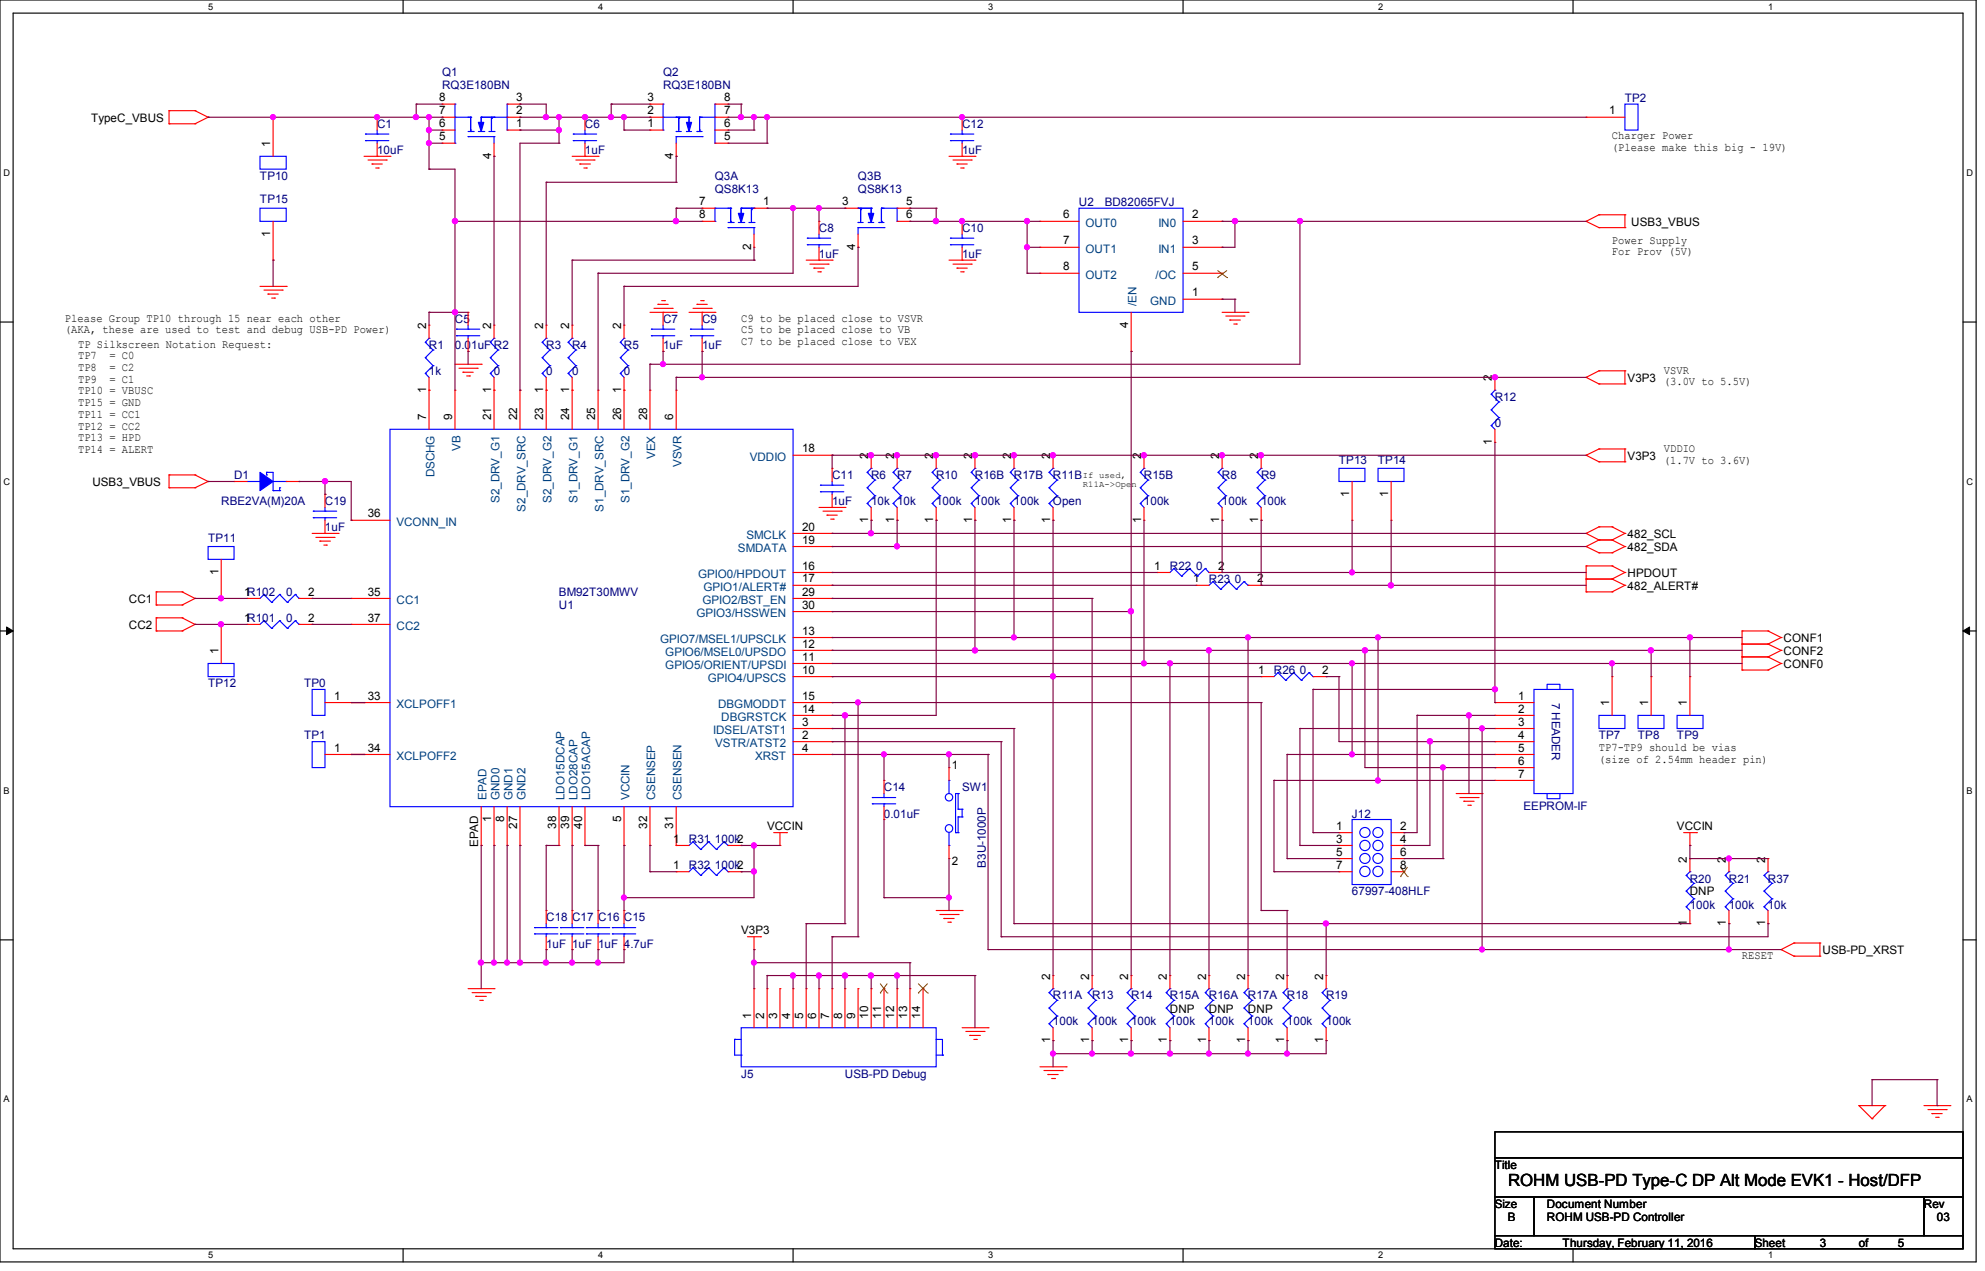
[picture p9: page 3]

Charger Power
(Please make this big - 19V)

Please Group TP10 through 15 near each other
(AKA, these are used to test and debug USB-PD Power)
TP Silkscreen Notation Request:
TP10 = VBUSC
TP15 = GND

C9 to be placed close to VSVR
C5 to be placed close to VB
C7 to be placed close to VEX

TP7-TP9 should be vias
(size of 2.54mm header pin)

Title
ROHM USB-PD Type-C DP Alt Mode EVK1 - Host/DFP

TX1- A3 | RX1- B10 | VBUS4 A4 | VBUS3 B9 | CC1 A5 | SBU2 B8 | D2+ A6 | D2- B7 | D1- A7 | D1+ B6 | SBU1 A8 | CC2 B5 | VBUS2 A9 | VBUS1 B4 | RX2- A10 | TX2- B3 | RX2+ A11 | TX2+ B2 | GND2 A12 | GND1 B1
VDD4 13 | TX- 12 | TX+ 11 | VDD3 10 | DP3- 9 | DP3+ 8 | VDD2 7 | DP2- 6 | DP2+ 5 | VDD1 4 | PGND ⁴¹ MODE 1

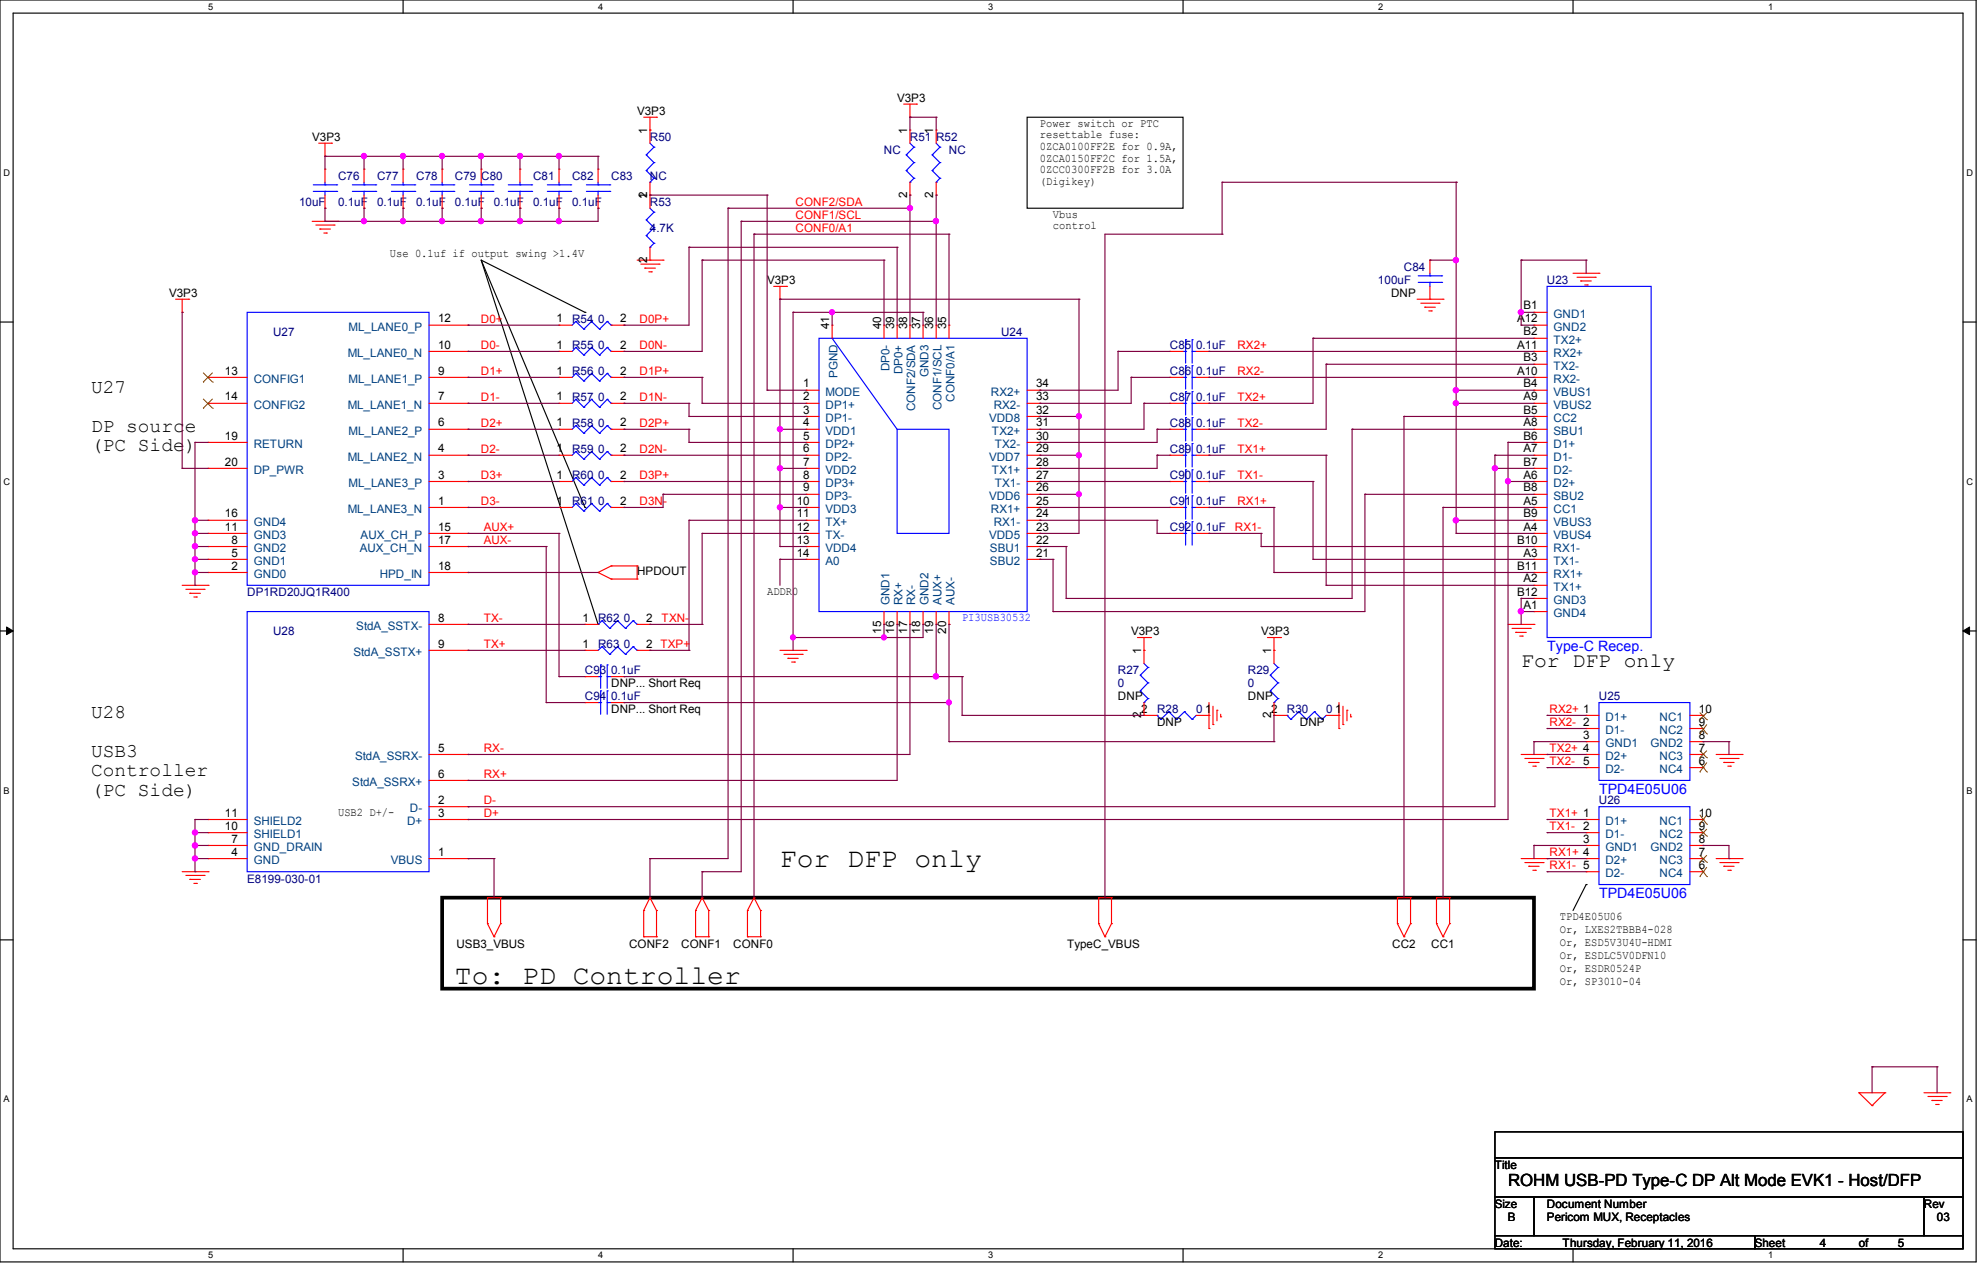
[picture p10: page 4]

CONF1/SCL
CONF0/A1

Use 0.1uf if output swing >1.4V

Title
ROHM USB-PD Type-C DP Alt Mode EVK1 - Host/DFP

# INPUT POWER USB to serial UART interface

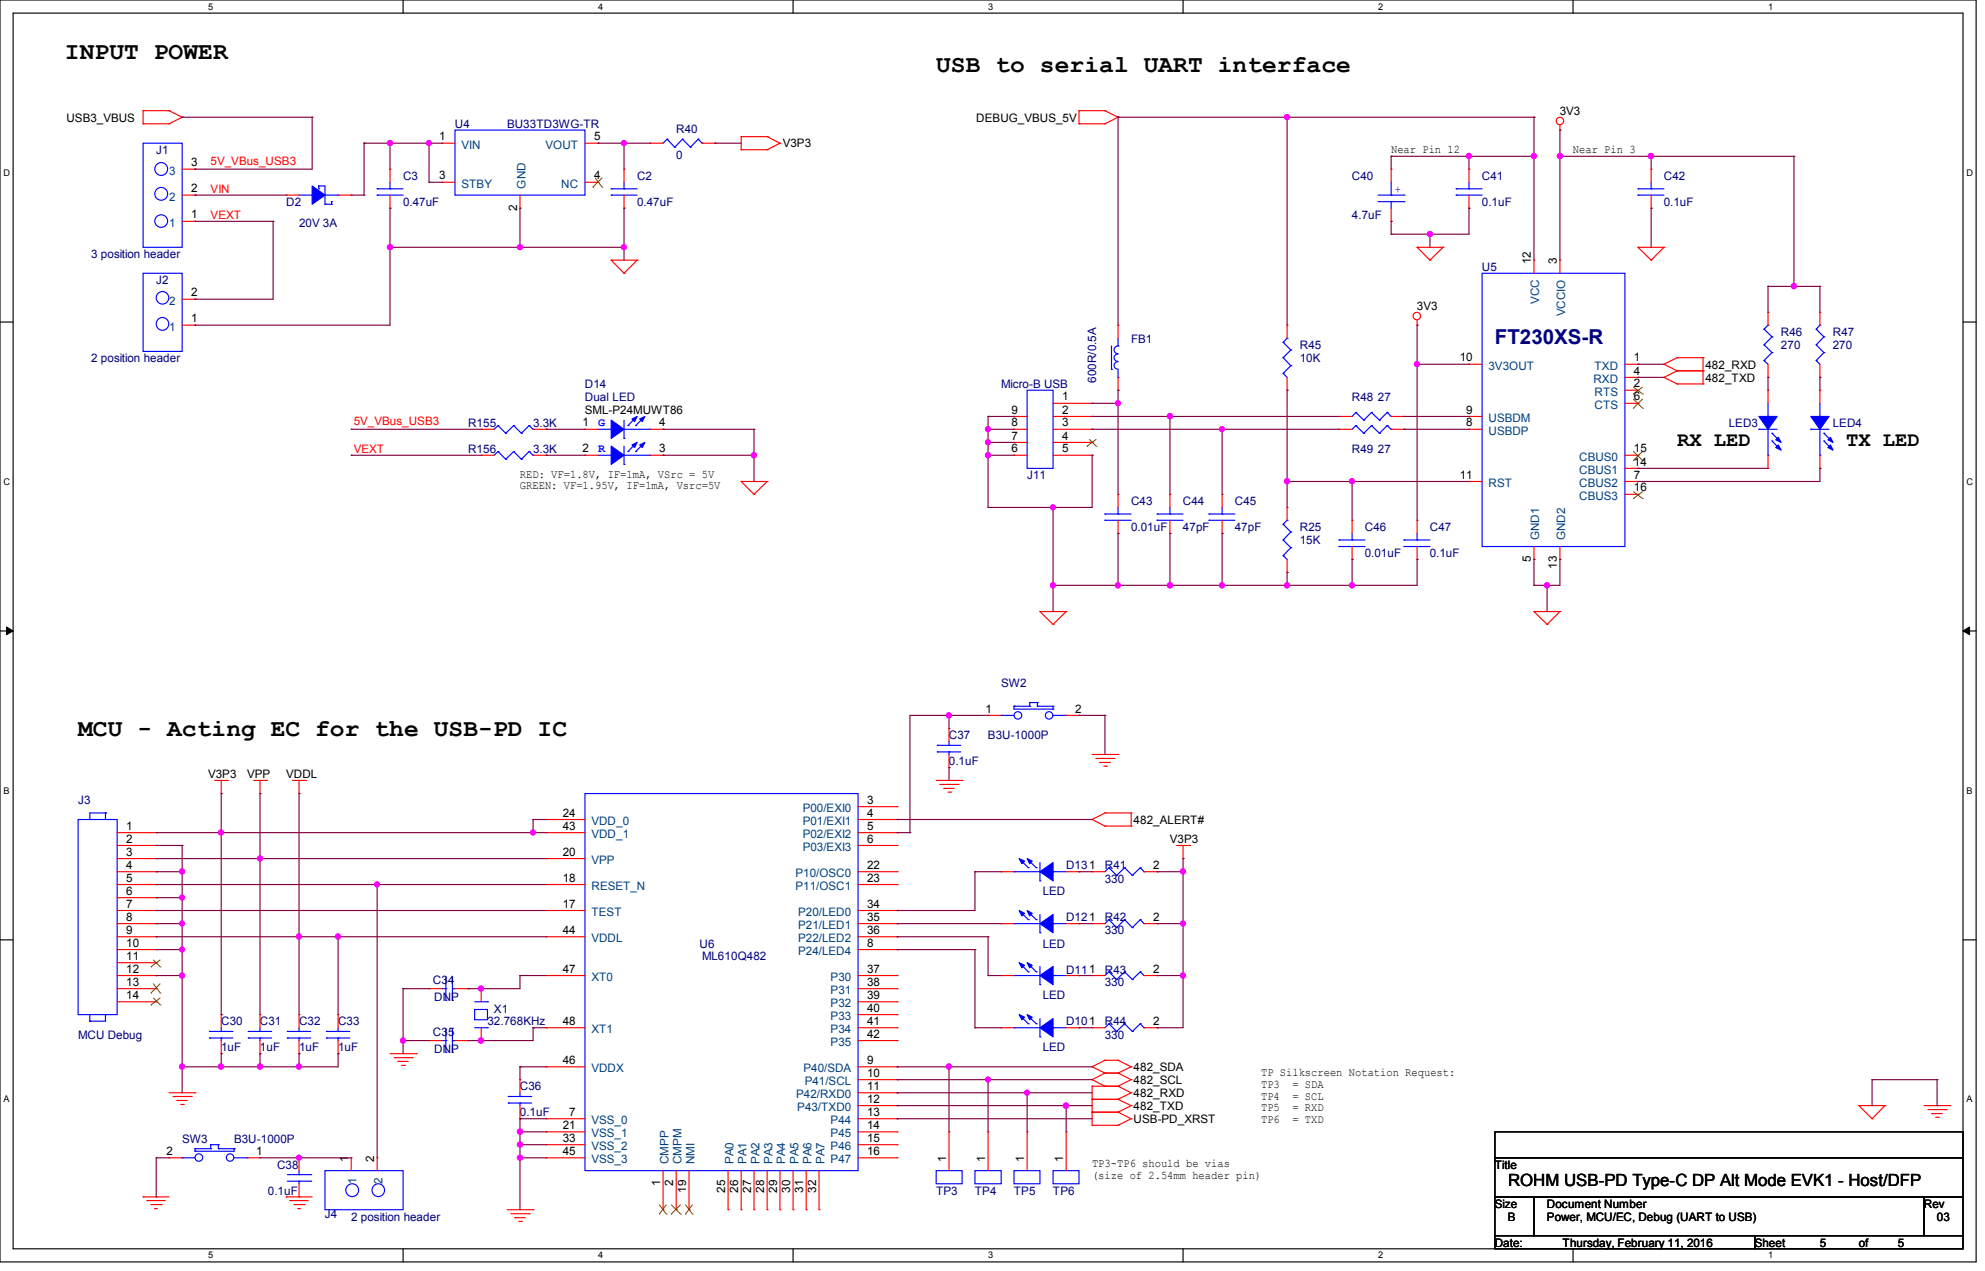
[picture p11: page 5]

8 3
7 4

RED: VF=1.8V, IF=1mA, VSrc = 5V
GREEN: VF=1.95V, IF=1mA, Vsrc=5V

MCU - Acting EC for the USB-PD IC

TP Silkscreen Notation Request:

TP3-TP6 should be vias
(size of 2.54mm header pin)

Title
ROHM USB-PD Type-C DP Alt Mode EVK1 - Host/DFP

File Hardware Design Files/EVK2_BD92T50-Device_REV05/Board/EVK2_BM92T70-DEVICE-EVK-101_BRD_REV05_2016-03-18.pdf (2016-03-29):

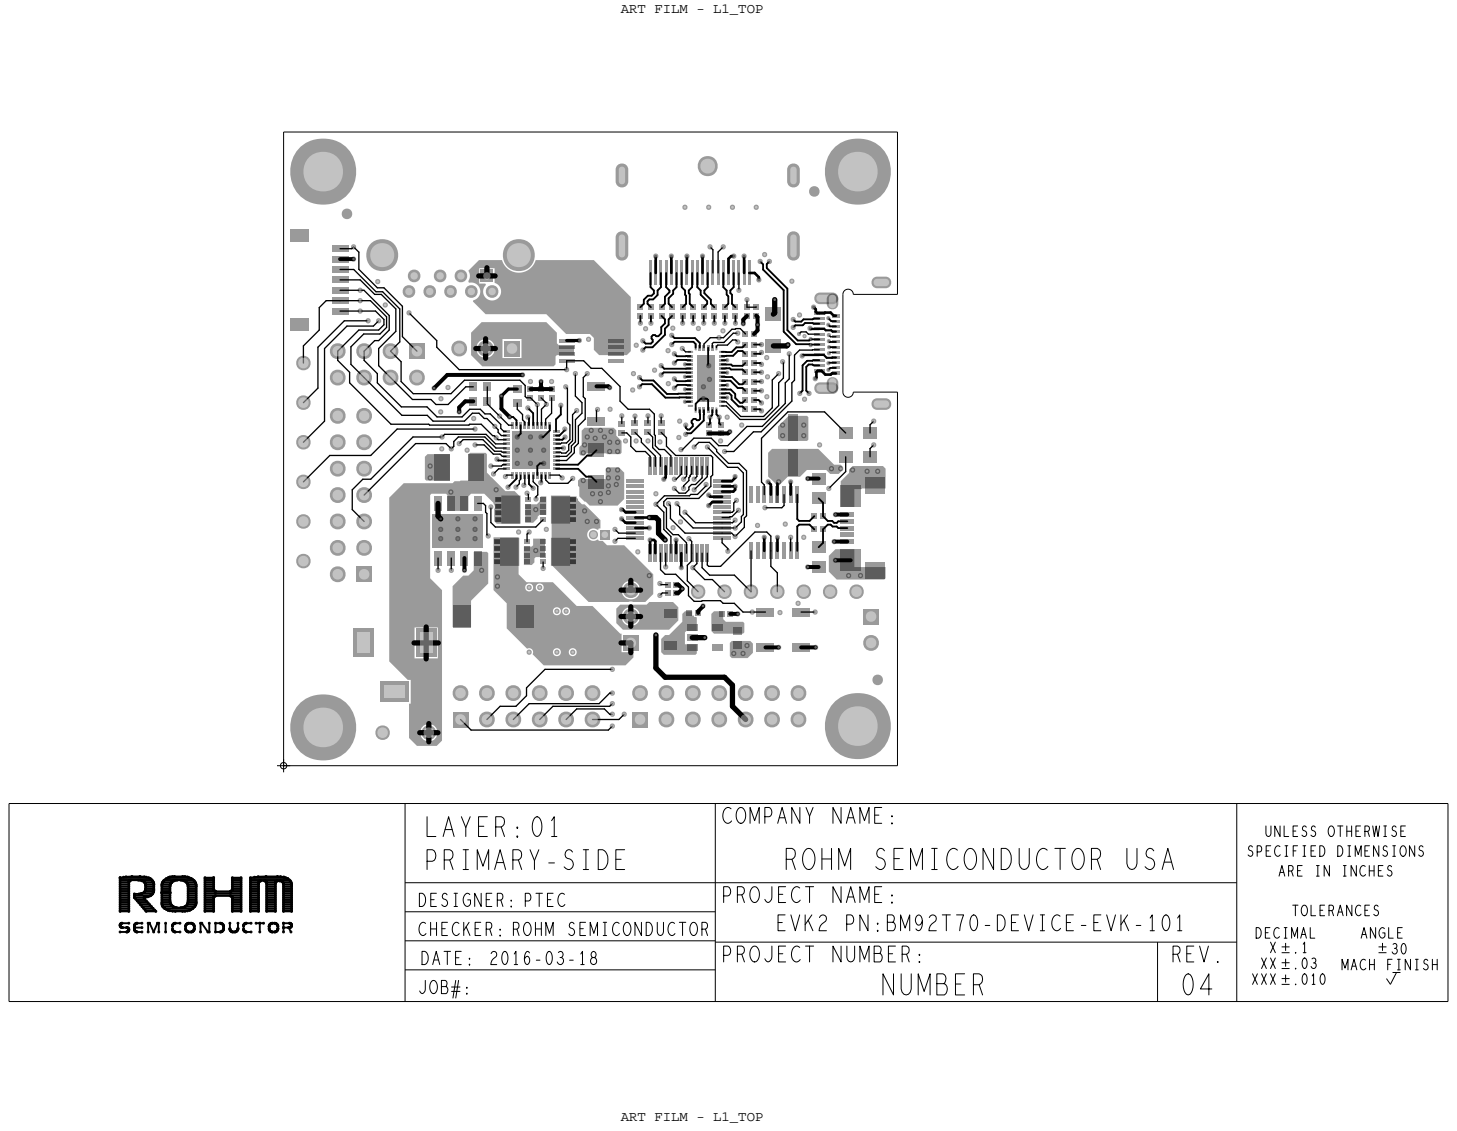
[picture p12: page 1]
ART FILM - L1_TOP; ANGLE; MACH FINISH; XXX; TOLERANCES; DECIMAL; REV.; ROHM; SEMICONDUCTOR USA; NUMBER; COMPANY NAME:; PROJECT; NAME:; NUMBER:; LAYER:; PRIMARY-SIDE; PTEC; DATE:; ROHM SEMICONDUCTOR; DESIGNER:; JOB#:; CHECKER:

UNLESS OTHERWISE
SPECIFIED DIMENSIONS
ARE IN INCHES

EVK2 PN:BM92T70-DEVICE-EVK-101

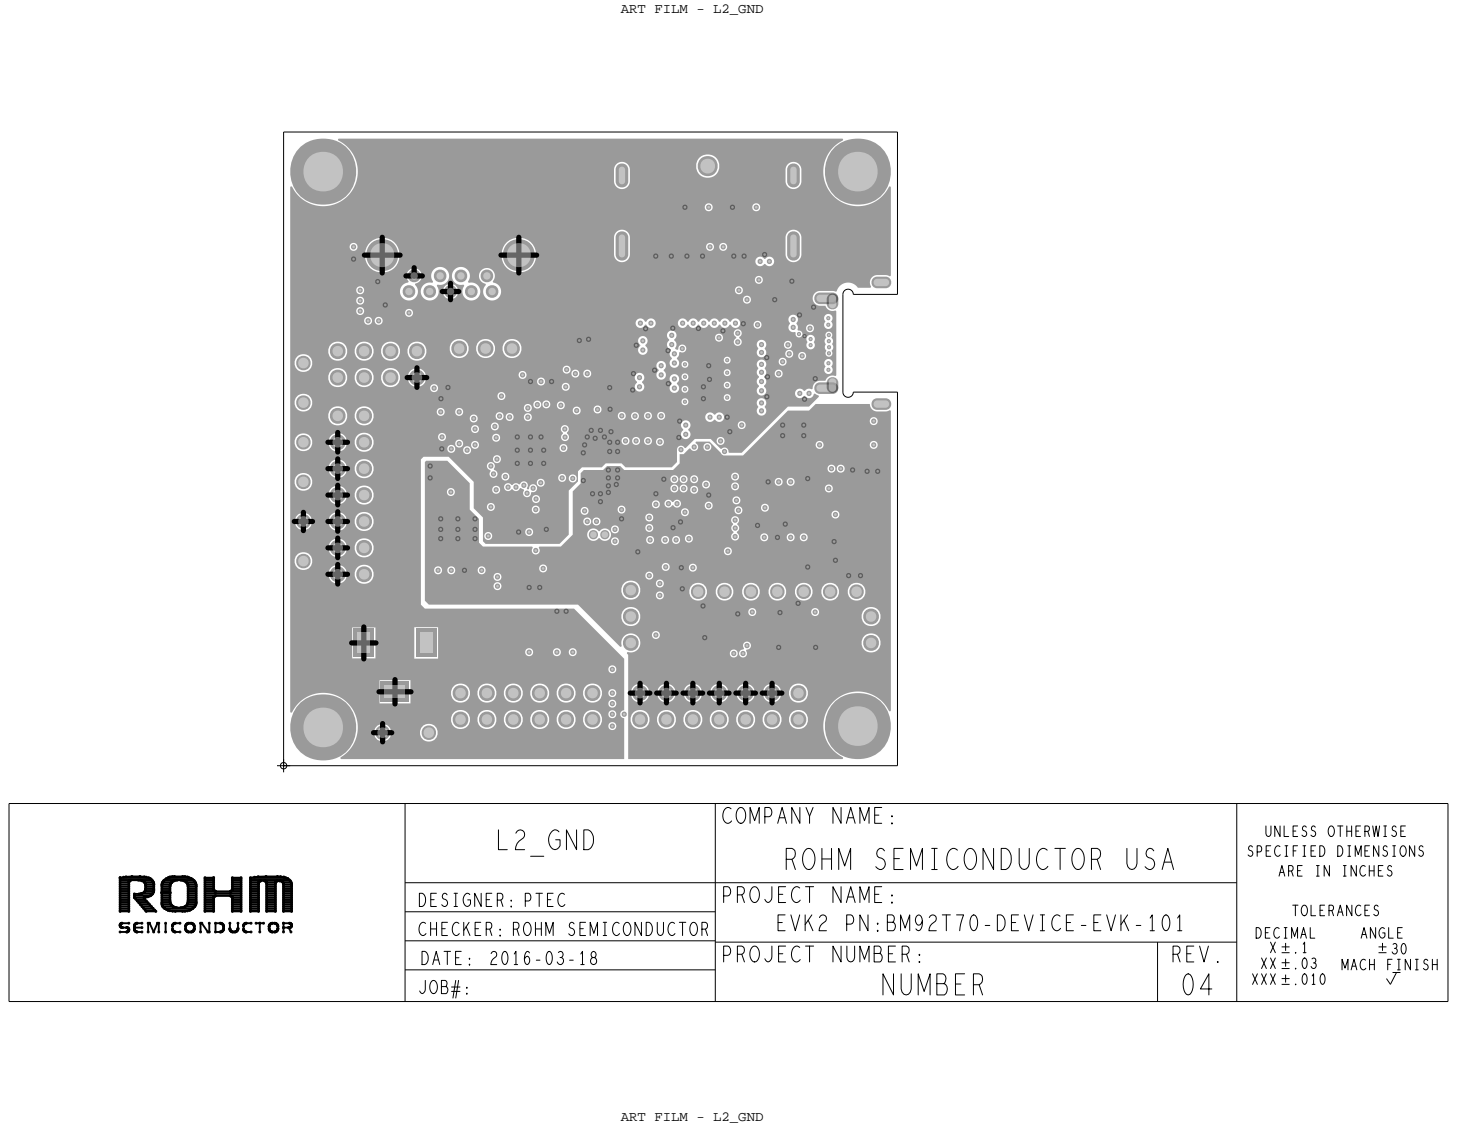
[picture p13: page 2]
ART FILM - L2_GND; ANGLE; MACH FINISH; XXX; TOLERANCES; DECIMAL; REV.; ROHM; SEMICONDUCTOR USA; NUMBER; COMPANY NAME:; PROJECT; NAME:; NUMBER:; L2_GND; PTEC; DATE:; ROHM SEMICONDUCTOR; DESIGNER:; JOB#:; CHECKER:

UNLESS OTHERWISE
SPECIFIED DIMENSIONS
ARE IN INCHES

EVK2 PN:BM92T70-DEVICE-EVK-101

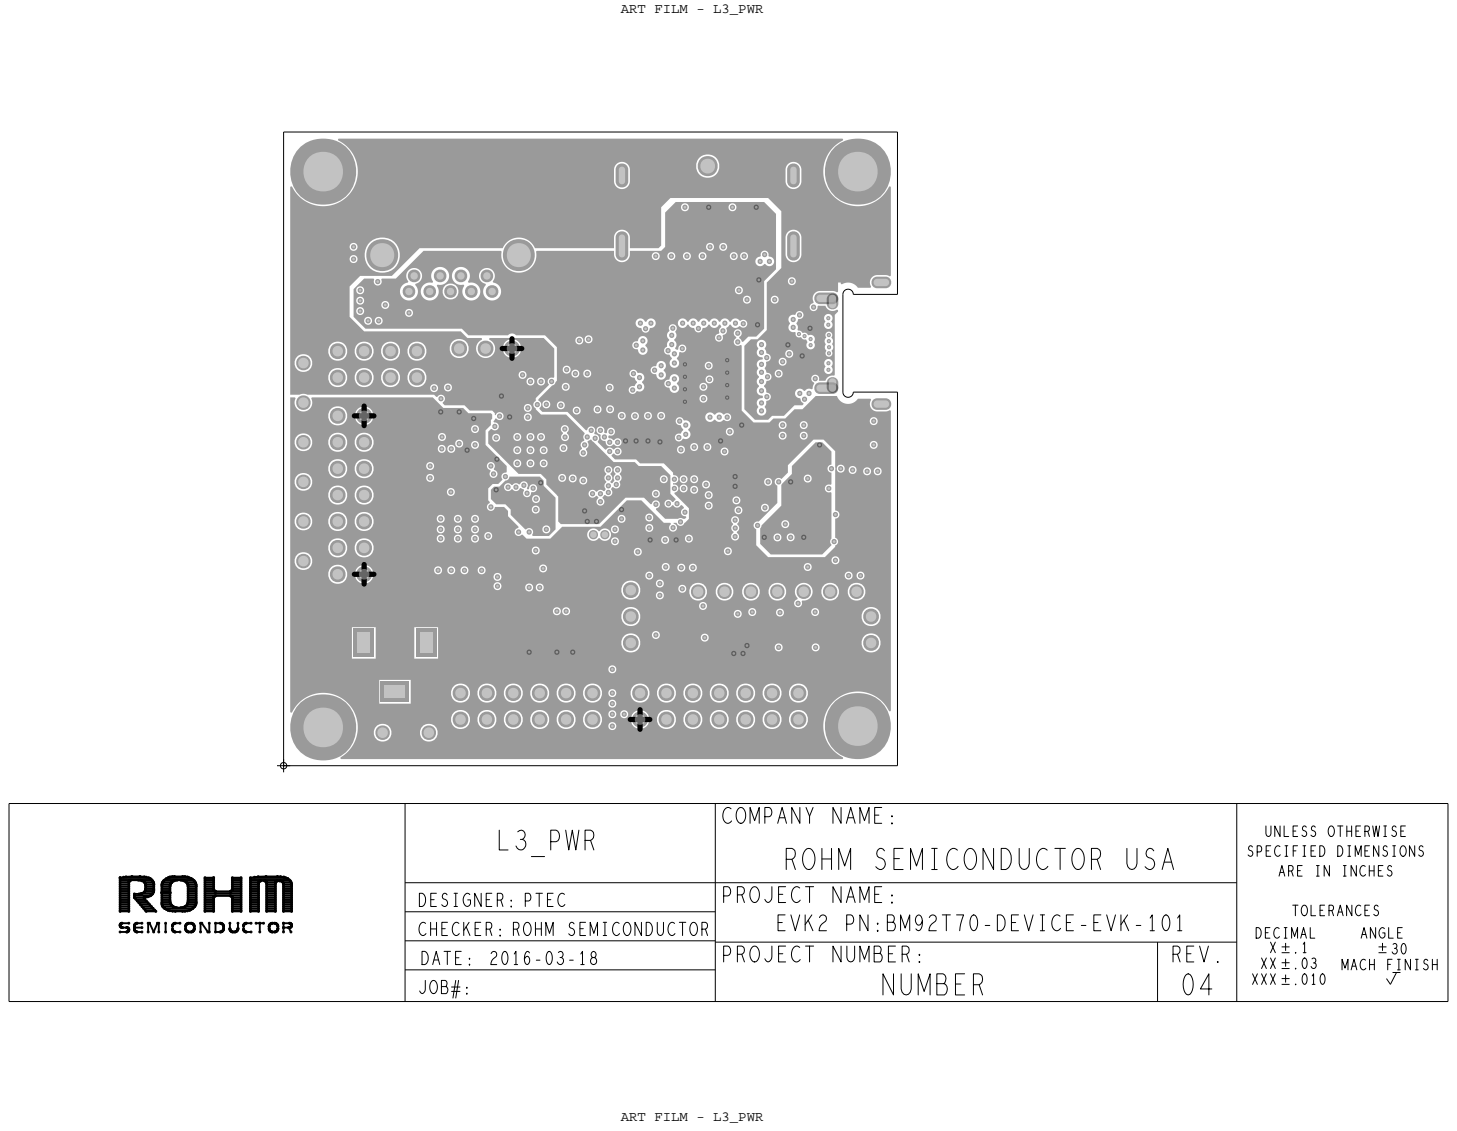
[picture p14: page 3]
ART FILM - L3_PWR; ANGLE; MACH FINISH; XXX; TOLERANCES; DECIMAL; REV.; ROHM; SEMICONDUCTOR USA; NUMBER; COMPANY NAME:; PROJECT; NAME:; NUMBER:; L3_PWR; PTEC; DATE:; ROHM SEMICONDUCTOR; DESIGNER:; JOB#:; CHECKER:

UNLESS OTHERWISE
SPECIFIED DIMENSIONS
ARE IN INCHES

EVK2 PN:BM92T70-DEVICE-EVK-101

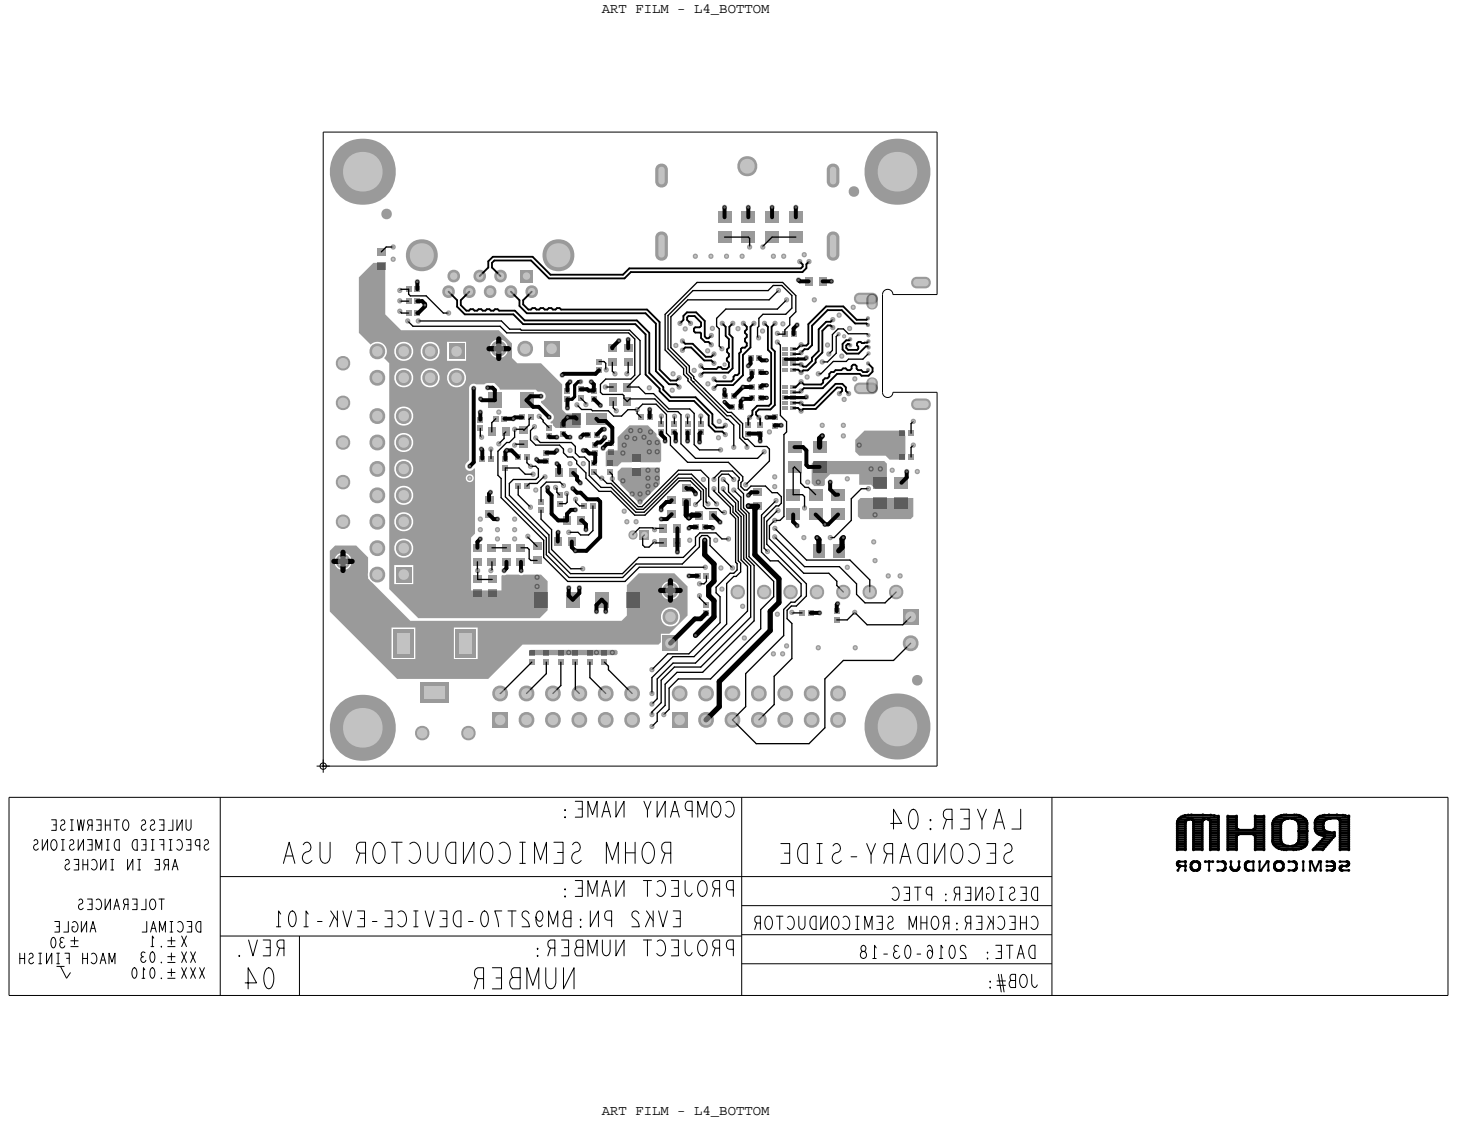
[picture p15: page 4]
ART FILM - L4_BOTTOM; DATE:; JOB#:; CHECKER:; DESIGNER:; 04 LAYER:; PTEC; SECONDARY-SIDE; ROHM SEMICONDUCTOR; COMPANY NAME:; PROJECT NAME:; PROJECT NUMBER:; NUMBER; REV. 04; XXX; DECIMAL .1 .03 .010; UNLESS OTHERWISE; SPECIFIED DIMENSIONS; TOLERANCES; ANGLE; 30 MACH FINISH

ARE IN INCHES

ROHM SEMICONDUCTOR USA

EVK2 PN:BM92T70-DEVICE-EVK-101

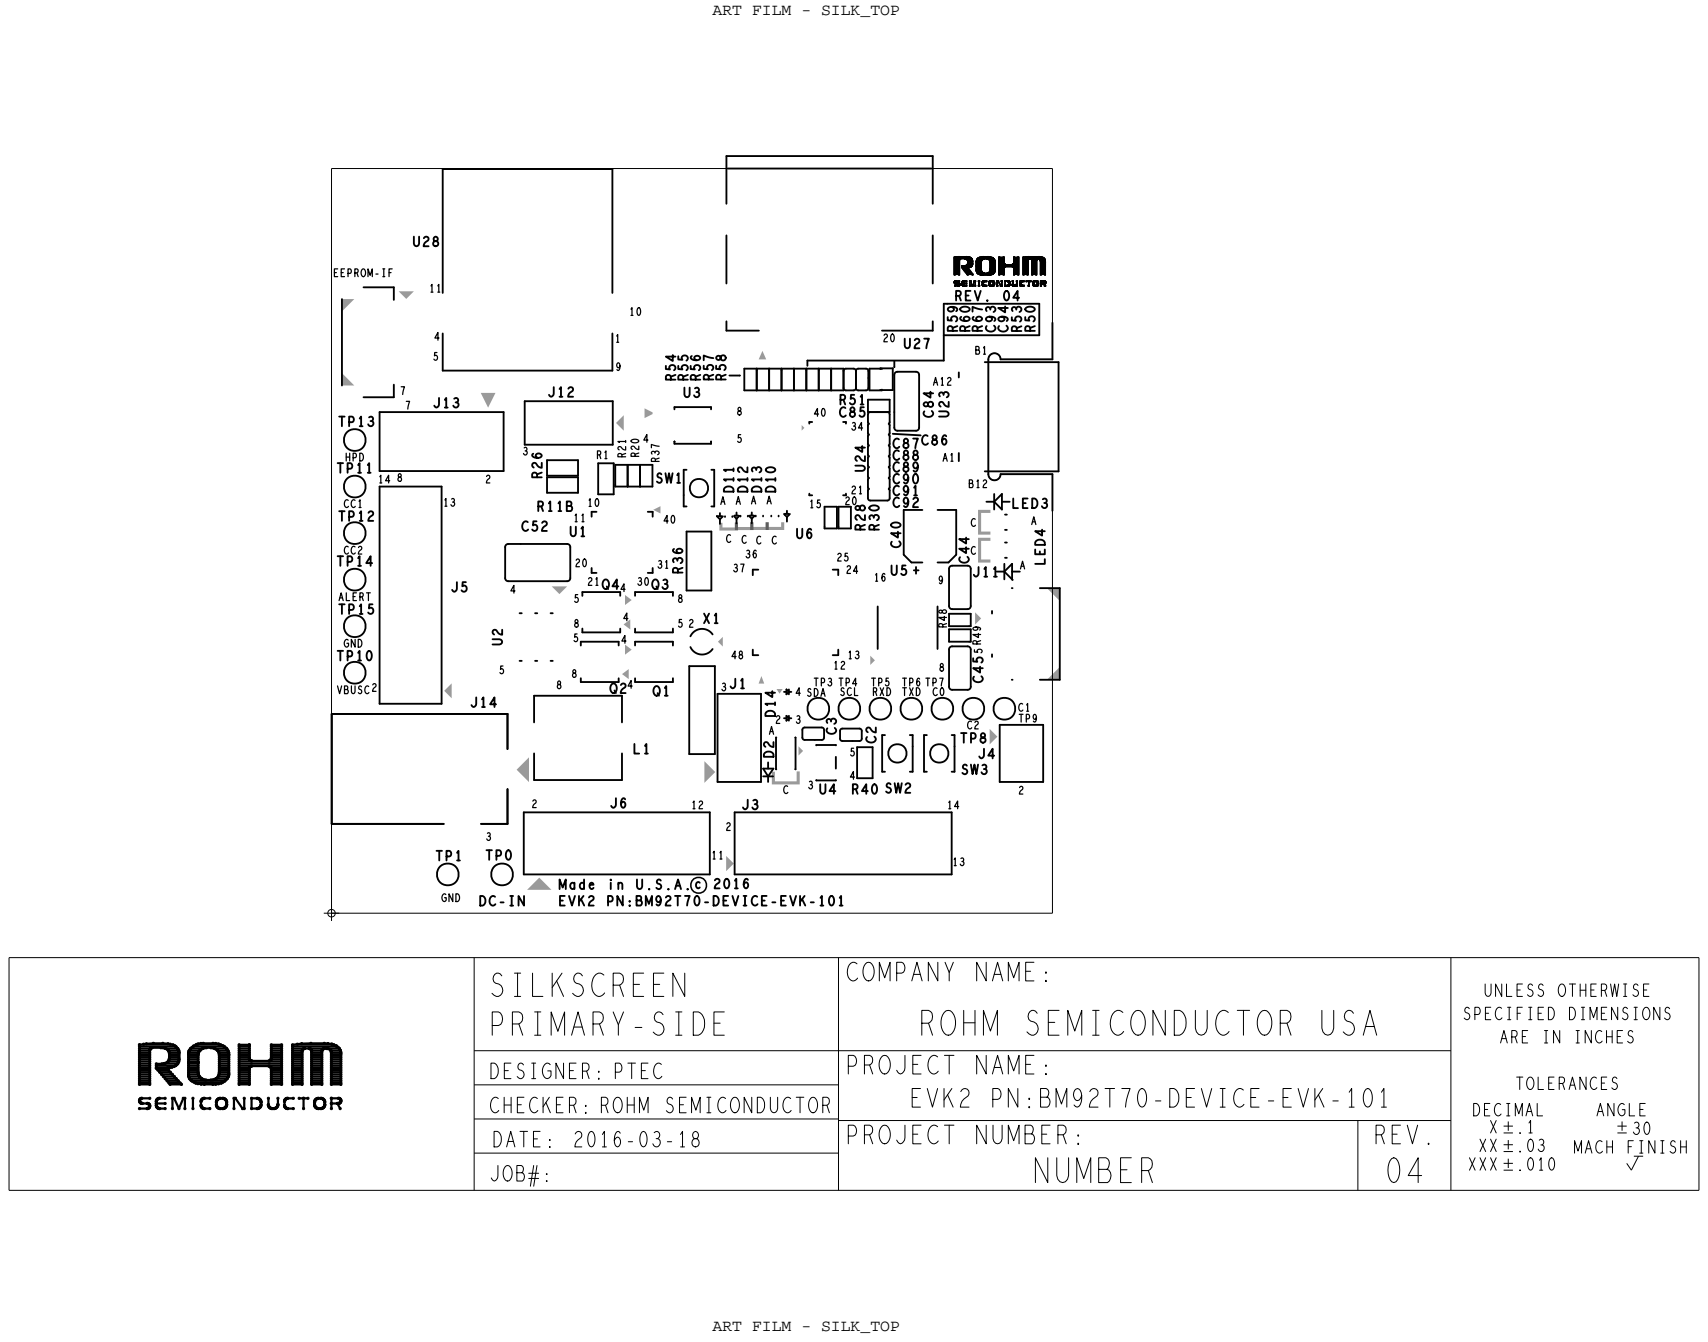
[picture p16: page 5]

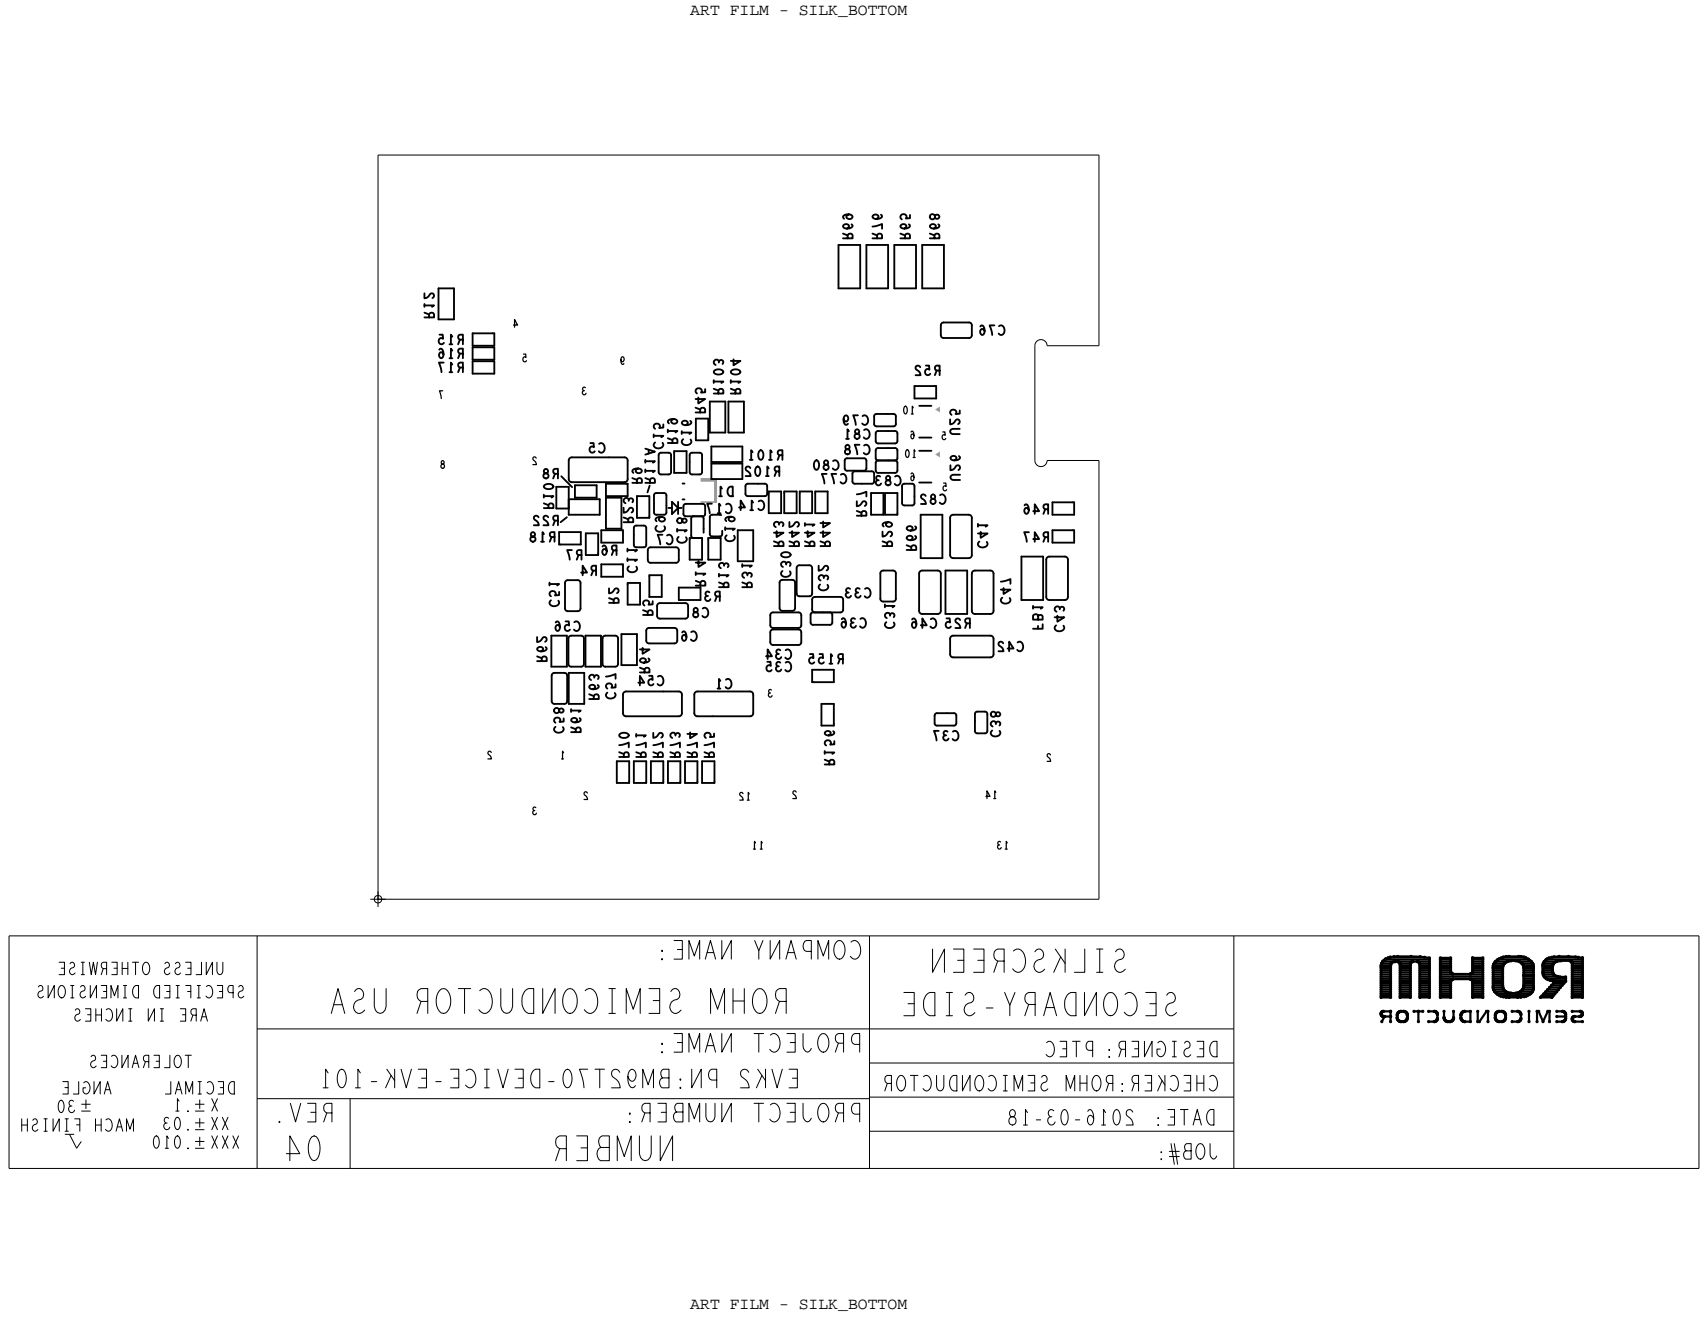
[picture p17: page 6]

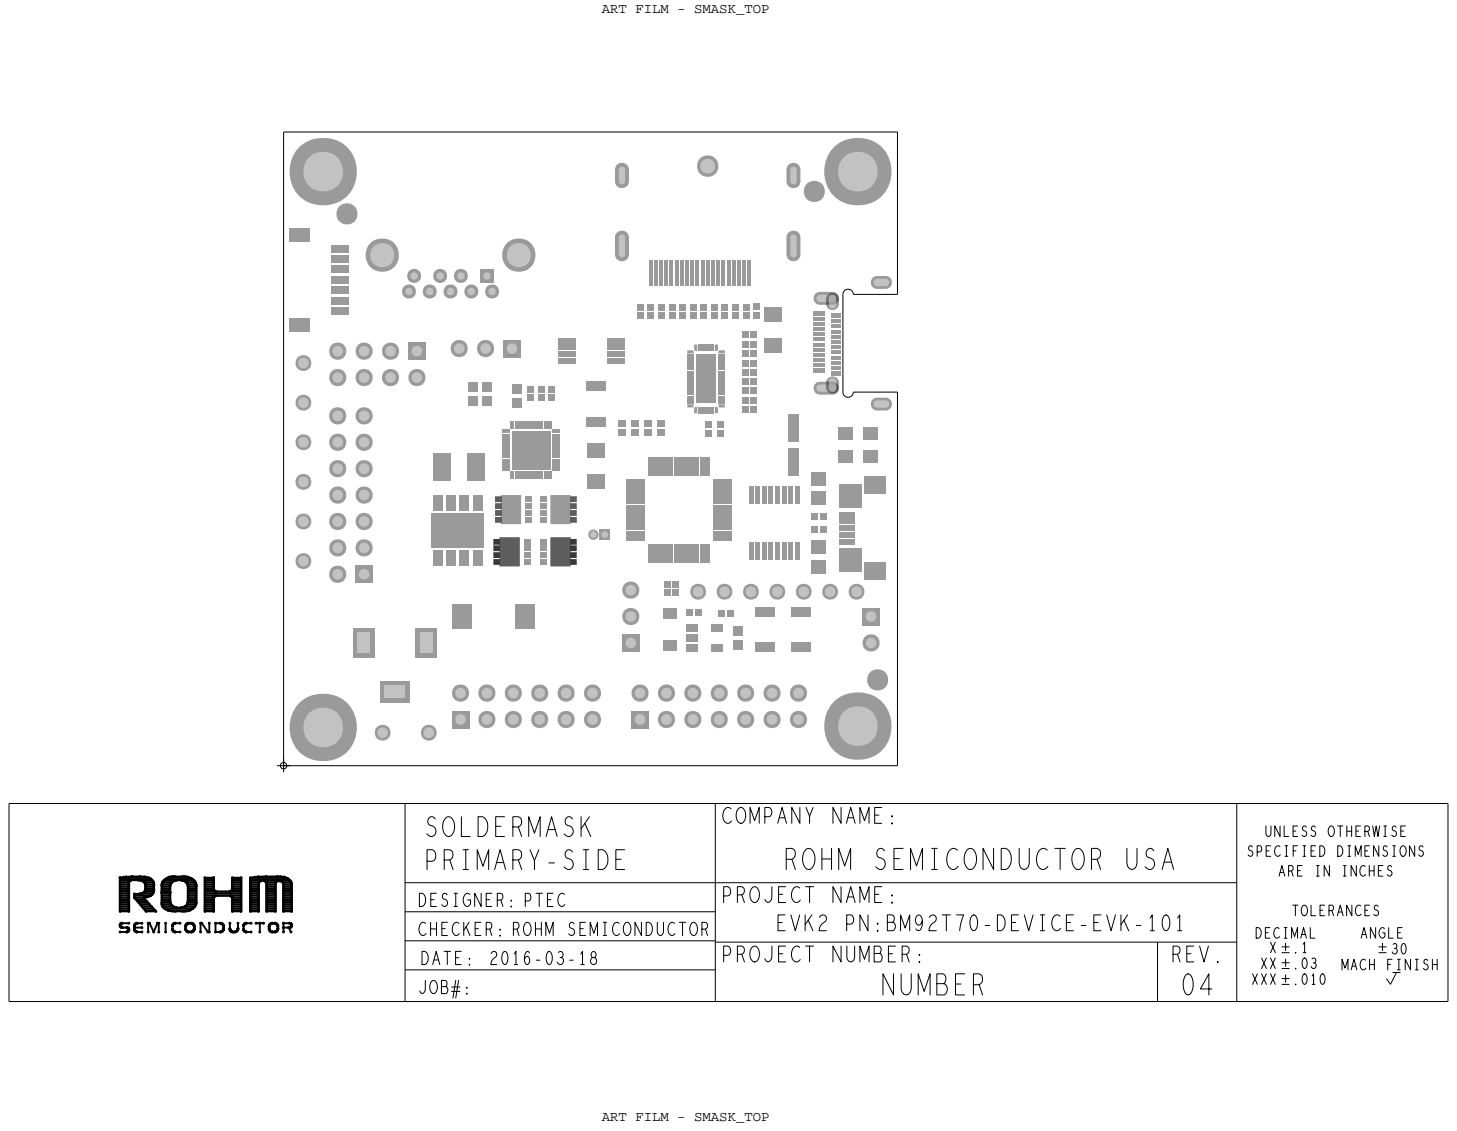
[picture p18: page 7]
ART FILM - SMASK_TOP; ANGLE; MACH FINISH; XXX; TOLERANCES; DECIMAL; REV.; ROHM; SEMICONDUCTOR USA; NUMBER; COMPANY NAME:; PROJECT; NAME:; NUMBER:; SOLDERMASK; PRIMARY-SIDE; PTEC; DATE:; ROHM SEMICONDUCTOR; DESIGNER:; JOB#:; CHECKER:

UNLESS OTHERWISE
SPECIFIED DIMENSIONS
ARE IN INCHES

EVK2 PN:BM92T70-DEVICE-EVK-101

ART FILM - SMASK_BOTTOM; DATE:; JOB#:; CHECKER:; DESIGNER:; SOLDERMASK; PTEC; SECONDARY-SIDE; ROHM SEMICONDUCTOR; COMPANY NAME:; PROJECT NAME:; PROJECT NUMBER:; NUMBER; REV. 04; XXX; DECIMAL .1 .03 .010; UNLESS OTHERWISE; SPECIFIED DIMENSIONS; TOLERANCES; ANGLE; 30 MACH FINISH

ARE IN INCHES

ROHM SEMICONDUCTOR USA

EVK2 PN:BM92T70-DEVICE-EVK-101

ART FILM - PASTE_TOP; ANGLE; MACH FINISH; XXX; TOLERANCES; DECIMAL; REV.; ROHM; SEMICONDUCTOR USA; NUMBER; COMPANY NAME:; PROJECT; NAME:; NUMBER:; PTEC; DATE:; ROHM SEMICONDUCTOR; PASTEMASK; PRIMARY-SIDE; DESIGNER:; JOB#:; CHECKER:

UNLESS OTHERWISE
SPECIFIED DIMENSIONS
ARE IN INCHES

EVK2 PN:BM92T70-DEVICE-EVK-101

ART FILM - PASTE_BOTTOM; DATE:; JOB#:; CHECKER:; DESIGNER:; PASTEMASK; PTEC; SECONDARY-SIDE; ROHM SEMICONDUCTOR; COMPANY NAME:; PROJECT NAME:; PROJECT NUMBER:; NUMBER; REV. 04; XXX; DECIMAL .1 .03 .010; UNLESS OTHERWISE; SPECIFIED DIMENSIONS; TOLERANCES; ANGLE; 30 MACH FINISH

ARE IN INCHES

ROHM SEMICONDUCTOR USA

EVK2 PN:BM92T70-DEVICE-EVK-101

D

2


REVISIONS

APPROVED

D

4


REVISIONS

REV | | APPROVED

D

2

MACH FINISH; ANGLE; XXX; DECIMAL; TOLERANCES; SHEET:; DATE; REV.; ROHM; SEMICONDUCTOR USA; COMPANY NAME:; PROJECT; NAME:; REVISIONS; PTEC; INITIAL; FAB DRAWING; JOB#:; DATE:; CHECKER:; DESIGNER:; REV; DESCRIPTION; applicable; specifications.; Customer; must be; advised; standards, and of; any specifications that cannot; met.; B. Producibility study - It; is the respondsibility of the; supplier; corrections; made or; recommendations to; ensure; conformance to; D. This; drawing; used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

ART FILM - FAB

LAYER STACKING DETAIL

APPROVED

Ref. Layer | Layer # | Layer Type | Copper Weight (Oz) | Copper Thickness (Mils) | Material Type - Ply | Dielectric Thickness (Mils) | Finished Line (Mils) | Diff. Gap (Mils) | Required Impedance (Ohms)

NOTES:
1. Specifications.
A. Fabricate IAW IPC600, latest revision.

Solder Mask | | | | 1.2
Plating | | | | 1.2

2 | 1 | TOP | 0.5 | 0.7

Prepreg | 4.4

2 | GND | 1 | 1.4

Core | 47

3 | PWR | 1 | 1.4

3 | 4 | BOT | 0.5 | 0.7

Plating | | | | | 1.2
Solder Mask | | | | | 1.2

Total Overal Thickness:

7. Electrical Test
B. Apply test stamp in non-legend area on solder side of PCB.
C. Test is required on both sides of the board.

8. Cleanliness
A. Boards shall be free of fiber glass dust or any other foreign material.
B. Finished boards must conform to 0.01 MG/IN max NAcL ionic contamination
as meaxured by the omega meter 600SMD.

10. Bow and Twist
Bow and twist to be .007 IN/IN or .090 max according to IPC-A-600D.

12. Inside corners should be rounded-off
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

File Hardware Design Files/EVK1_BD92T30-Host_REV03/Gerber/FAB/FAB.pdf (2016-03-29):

D

2

TOLERANCES; MACH FINISH; ANGLE; XXX; DECIMAL; REV.; SHEET:; DATE; PROJECT; NAME:; COMPANY NAME:; ROHM; SEMICONDUCTOR USA; NUMBER; FAB NUMBER:; REVISIONS; PTEC; INITIAL; DESIGNER:; FAB DRAWING; JOB#:; DATE:; CHECKER:; REV; DESCRIPTION; applicable; specifications.; Customer; must be; advised; standards, and of; any specifications that cannot; met.; B. Producibility study - It; is the respondsibility of the; supplier; corrections; made or; recommendations to; ensure; conformance to; D. This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

ART FILM - FAB

LAYER STACKING DETAIL

APPROVED

Ref. Layer | Layer # | Type | Copper Weight Layer (Oz) | Copper Thickness (Mils) | Material Type - Ply | Dielectric Thickness (Mils) | Finished Line (Mils) | Diff. Gap (Mils) | Required Impedance (Ohms)

NOTES:
1. Specifications.
A. Fabricate IAW IPC600, latest revision.

Solder Mask | | | | 1.2
Plating | | | | 1.2

2 | 1 | TOP | 0.5 | 0.7

Prepreg | 4.4

2 | GND | 1 | 1.4

Core | 47

3 | PWR | 1 | 1.4

3 | 4 | BOT | 0.5 | 0.7

Plating | | | | | 1.2
Solder Mask | | | | | 1.2

Total Overal Thickness:

9. Packaging
There shall be a max of 25 units per package, individually wrapped,
material to prevend shipping damage.

10. Bow and Twist
Bow and twist to be .007 IN/IN or .090 max according to IPC-A-600D.

12. Inside corners should be rounded-off

13. Changes to board geometries and apertures are not
allowed unless they are approved by customer.

14. Rounding is allowed on 90 degree corners with the size of
standard routing bit.

UNLESS OTHERWISE
SPECIFIED DIMENSIONS
ARE IN INCHES

EVK1 PN:BM92T30-HOST-EVK-101

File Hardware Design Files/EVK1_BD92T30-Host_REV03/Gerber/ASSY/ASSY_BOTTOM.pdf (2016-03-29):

# ART FILM - ASSY_BOTTOM

D


REVISIONS

APPROVED

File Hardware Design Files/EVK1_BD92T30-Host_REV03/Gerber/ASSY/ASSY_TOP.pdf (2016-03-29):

# ART FILM - ASSY_TOP

D


REVISIONS

APPROVED

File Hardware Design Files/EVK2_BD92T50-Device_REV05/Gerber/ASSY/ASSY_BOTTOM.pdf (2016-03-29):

# ART FILM - ASSY_BOTTOM

D


REVISIONS

REV | | APPROVED

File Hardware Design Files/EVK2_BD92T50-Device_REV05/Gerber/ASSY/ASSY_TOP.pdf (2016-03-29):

# ART FILM - ASSY_TOP

D


REVISIONS

APPROVED

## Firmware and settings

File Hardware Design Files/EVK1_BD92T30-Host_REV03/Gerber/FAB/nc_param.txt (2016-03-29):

INTEGER-PLACES         2
DECIMAL-PLACES         4
X-OFFSET               0.000000
Y-OFFSET               0.000000
FEEDRATE               1
COORDINATES            ABSOLUTE
OUTPUT-UNITS           ENGLISH
TOOL-ORDER             INCREASING
REPEAT-CODES           YES
SUPPRESS-LEAD-ZEROES   NO
SUPPRESS-TRAIL-ZEROES  NO
SUPPRESS-EQUAL         NO
TOOL-SELECT            NO
OPTIMIZE_DRILLING      NO
ENHANCED_EXCELLON      NO
HEADER                 none
LEADER                 12
CODE                   ASCII
SEPARATE               NO
SEPARATE-ROUTING       NO
DRILLING               LAYER-PAIR
BACKDRILL              NO
CAVITY                 NO

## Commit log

2016-03-29 First Commit - Major Collateral Addition
    Adding the Major Points of Collateral (Datasheets, HW Designs) to get
    this Repository Started
    [ROHM_USB-PD_DP-ALTMODE_EVK1+2_SCH_REV04_2016-02-23.DSN, ROHM_USB-PD_DP-ALTMODE_EVK1+2_SCH_REV05_2016-03-17.DSN, ROHM_USB-PD_DP-ALTMODE_EVK1_BOM_REV03_2016-02-2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]
2016-04-02 Cleaned Up Repository
    Removed Erroneous directories, adjusted Readme
    [ROHM_USB-PD_DP-ALTMODE_EVK1+2_SCH_REV04_2016-02-23.DSN, ROHM_USB-PD_DP-ALTMODE_EVK1+2_SCH_REV05_2016-03-17.DSN, ROHM_USB-PD_DP-ALTMODE_EVK1_BOM_REV03_2016-02-2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]
2016-04-07 Fixed Readme and Board Manual
    Added Video References, Updated Board Manual
